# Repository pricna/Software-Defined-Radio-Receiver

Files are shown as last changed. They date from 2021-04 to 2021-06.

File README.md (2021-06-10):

# Software-Defined-Radio-Receiver
Software Defined Radio (SDR) receiver created in partial fulfillments of ENGR 357 "Engineering Electronics II" at Walla Walla University.

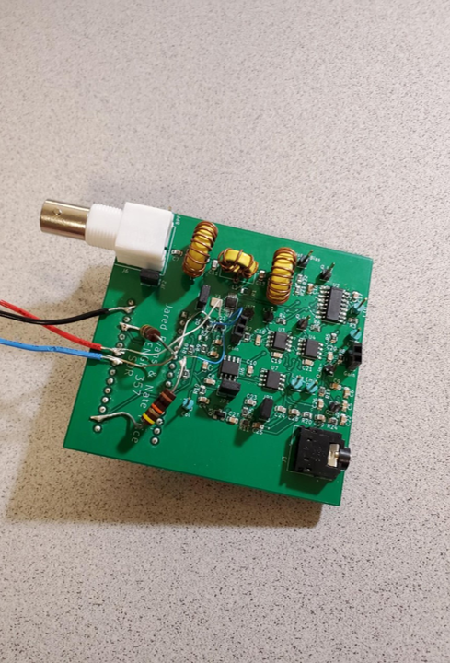
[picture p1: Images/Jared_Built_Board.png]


**Introduction:** This SDR receiver was designed to be simple and low cost, operate in the 10 MHz to 16 MHz frequency range, and also meet specific design criteria specified below. We ([Nate Price](https://github.com/pricna) and [Jared Evans](https://github.com/jred-KiCAD)), designed, assembled, and tested the SDR receiver to be used with a free open source SDR software, called Quisk. More information on the design, issues, testing, and software aspects of this project can be found on the [wiki page](https://github.com/pricna/Software-Defined-Radio-Receiver/wiki).

**Navigation:** 
- The Descriptions folder contains our circuit description for Miles
- The Images folder contains a variety of images of our board, PCB, and schematic
- The PCB Files folder contains some versions of our PCB, separated from the rest of the schematic files
- The Project Files folder contains our Bill of Materials and project files for v1.1
- The Schematic files folder contains pdfs of all of our schematic revisions, as well as project files for each of them
- The latest schematic can be found [here](https://github.com/pricna/Software-Defined-Radio-Receiver/tree/main/Schematic%20files/Project%20Files/v2.0/ENGR357_Project)

**Credits:** Much of this work builds on work described in [A Comparison of Affordable, Self-Assembled Software-Defined Radio Receivers Using Quadrature Sampling Down-Conversion](http://fweb.wallawalla.edu/~frohro/ClassHandouts/Electronics/A%20Comparison%20of%20Affordable,%20Self-Assembled%20%20Software-Defined%20Radio%20Receivers%20Using%20Quadrature%20Sampling%20Down-Conversion.pdf) by the authors [Caleb Froelich](https://github.com/froeca), [Konrad McClure](https://github.com/KonradMcClure), [Joshua Silver](https://github.com/JoshSilver8), [Jordyn Watkins](https://github.com/greenjacketgirl), and our professor, [Dr. Rob Frohne](https://github.com/frohro).

**Project Results:** We worked on two boards, one needs to have a FET replaced, which is a bit difficult with all the other connections we added to fix some PCB errors. It also might need further work, but it is unknown if there are more errors because the Arduino and Si5351 were not communicating. We were able to get the other board working. It produces I/Q signals 90 degrees out of face, has a sensitivity less than .1uV, and was successfully able to pick up signals when connected to the antenna with the Quisk software running. Take a look at [this video](https://www.youtube.com/watch?v=M_2Oau0vji8) to see the working radio!

## Further Information

(The information below is also covered in the [wiki page](https://github.com/pricna/Software-Defined-Radio-Receiver/wiki) (in sections). The wiki page also has some extra pages with information not in this document with milestones and generally useful information.

## 1. Hardware Design

## Block Diagram 
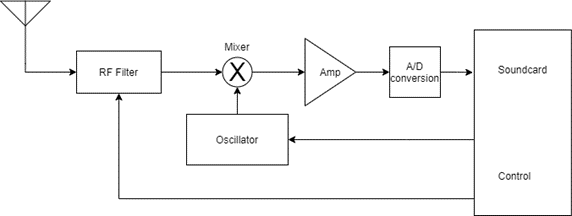
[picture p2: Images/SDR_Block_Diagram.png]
 

The block diagram was designed to help us get a better understanding of all the portions that needed to be designed for this project. Given that we had the benefit of seeing what other groups had previously worked on, figuring this out was relatively simple even though it does not fully match our final design.

## Bandpass Filter 
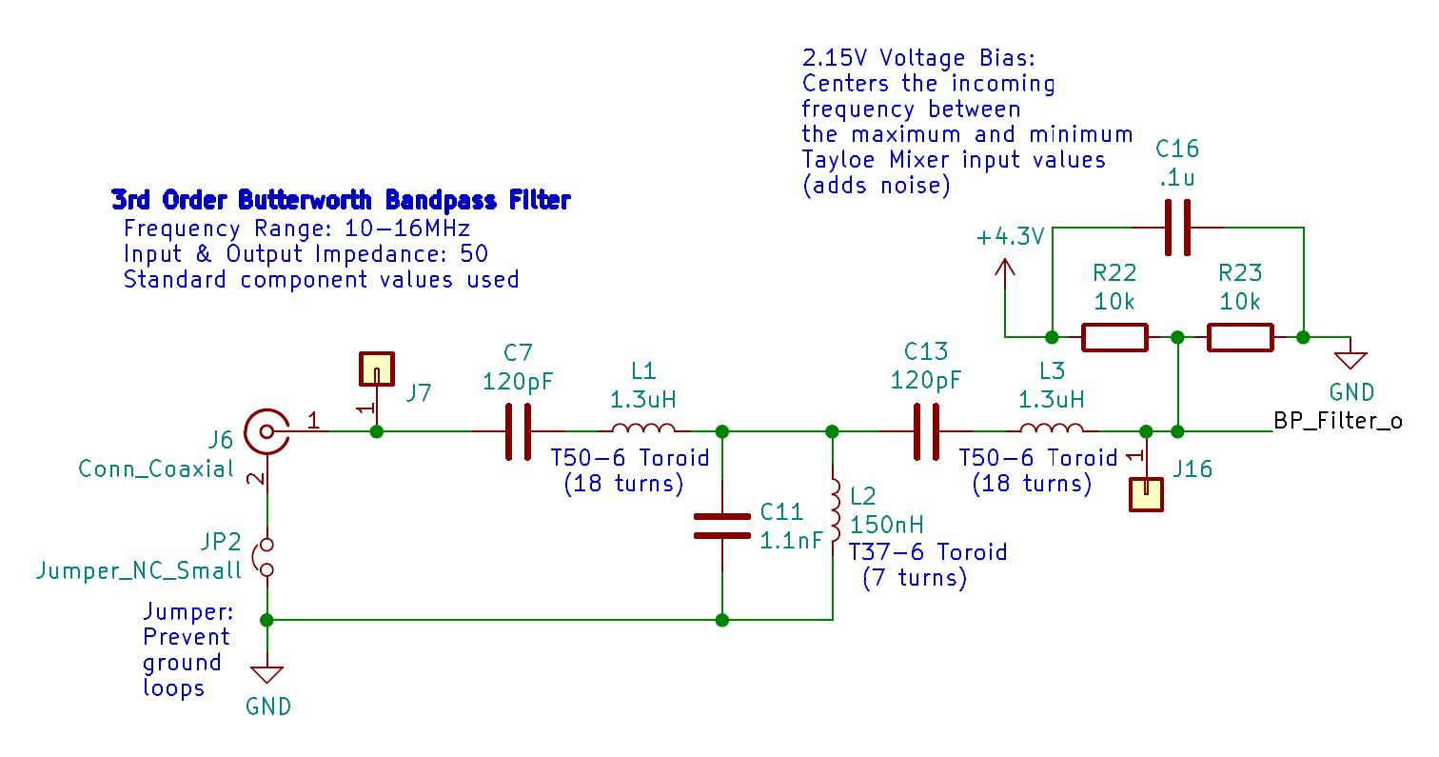
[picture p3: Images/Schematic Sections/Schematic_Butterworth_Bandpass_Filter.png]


The bandpass filter was partially based on the work done previously by [Caleb Froelich](https://github.com/froeca) and [Konrad McClure](https://github.com/KonradMcClure). We used the same tool that they used, [rf-tools](https://rf-tools.com/lc-filter/), to calculate the necessary values for a 3rd-order Butterworth bandpass filter for a lower cutoff frequency of 10 MHz and an upper cutoff frequency of 16 MHz. The number of turns for the toroids was determined to be 3nH per turns^2 for the Ts7-6 and 4nH per turns^2 for the T50-6. The 2.15V voltage bias part on the end is used to center the incoming frequency between the maximum and minimum Tayloe Mixer input values, which adds noise, but we ultimately determined that having that part is more useful here. 

**Calculations:**
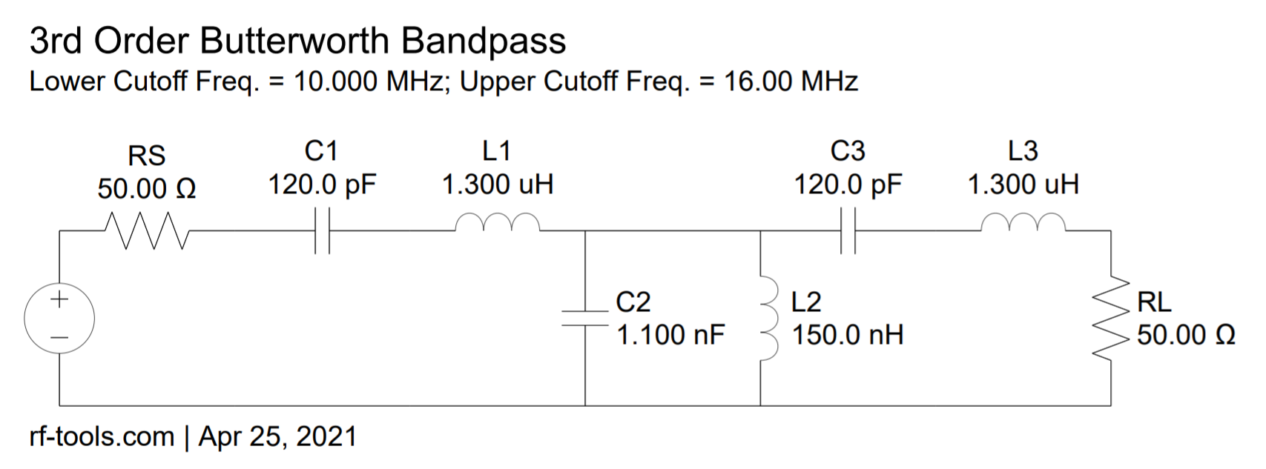
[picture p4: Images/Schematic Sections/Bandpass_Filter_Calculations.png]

  
## Instrumentation Amplifier 
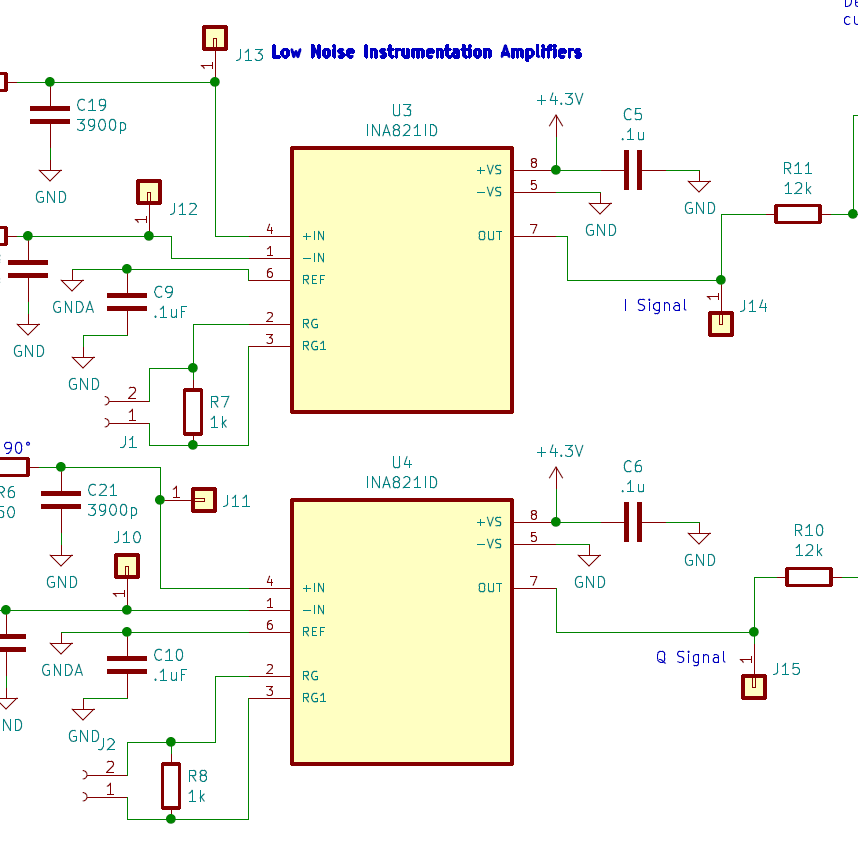
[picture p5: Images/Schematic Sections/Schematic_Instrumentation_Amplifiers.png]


The instrumentation design is very similar to the [Caleb](https://github.com/froeca) and [Konrad](https://github.com/KonradMcClure) design. They designed it to work in a way such that the 0° and 180° signals, and the 90° and 270° are are differentially summed by the INA821ID Instrumentation Amplifiers.

## Tayloe Mixer 
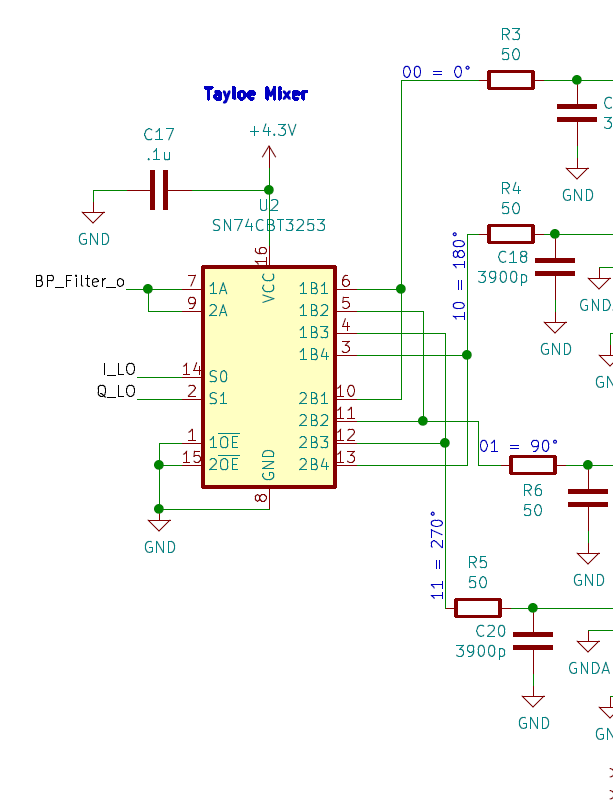
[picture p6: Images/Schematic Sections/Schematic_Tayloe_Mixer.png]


The Tayloe mixer design is once again very similar. We decided that we did not need to re-determine how to set up the connections to get 0° on 00, 90° on 01, and so on.

## Voltage Smoother 
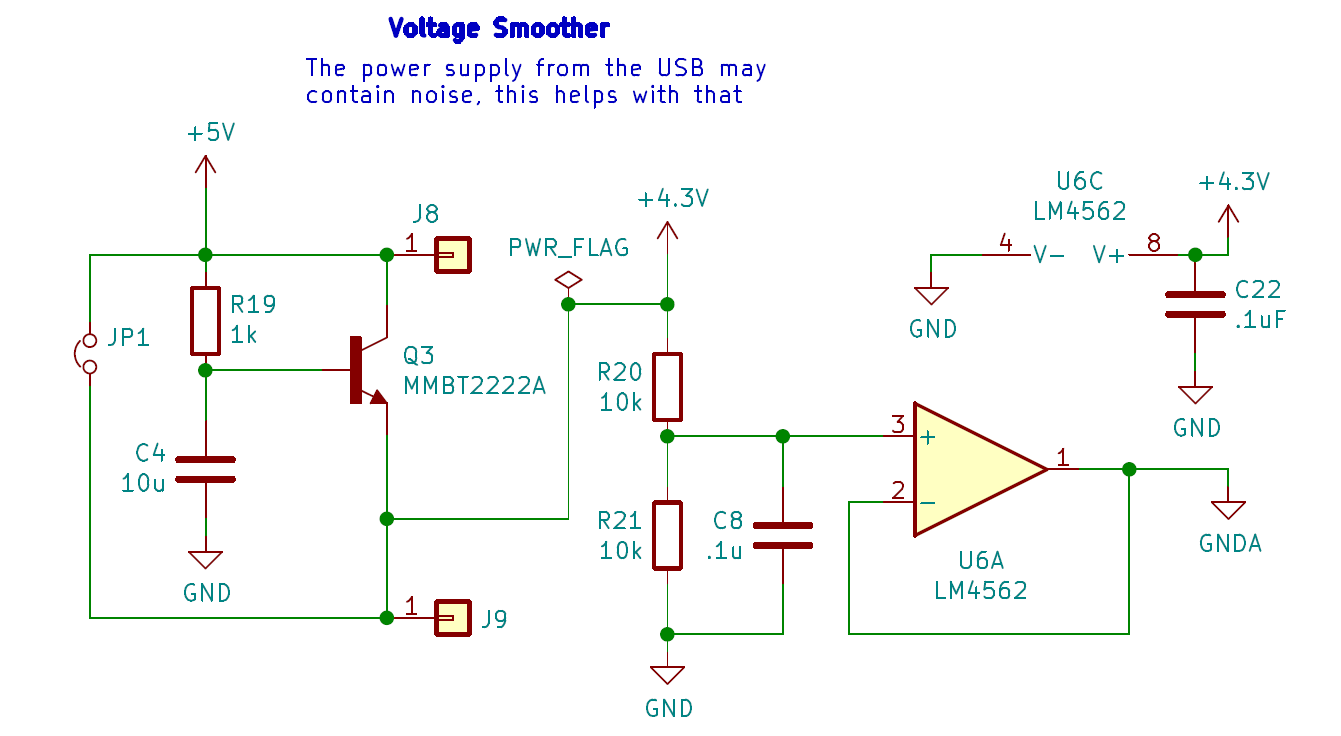
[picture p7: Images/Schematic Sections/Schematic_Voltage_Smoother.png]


Once again, this is something the previous group used to reduce some of the noise that resulted from the constant switching in the computer. Since for this project, some additional noise reduction seemed particularly useful, we pulled also used it for our design.

## Local Oscillator 
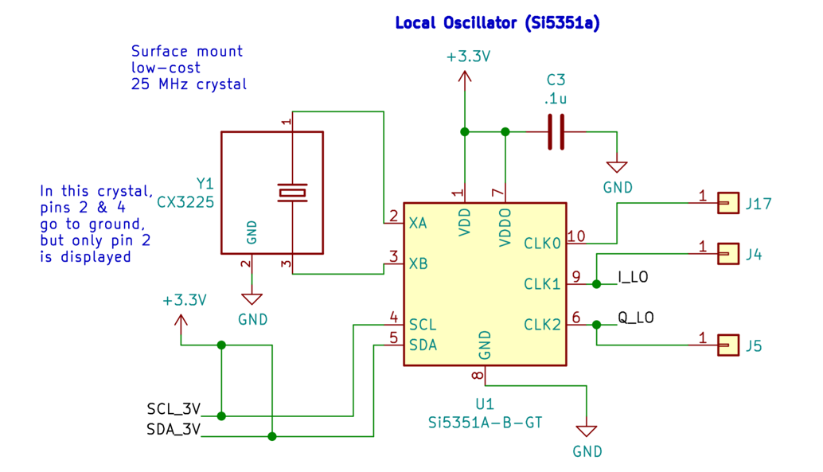
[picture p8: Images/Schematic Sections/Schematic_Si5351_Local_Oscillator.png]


As the previous group used a Johnson counter, the local oscillator needed to be updated for this project, since Dr. Frohne said it was unnecessary. A 3.3V connection was added to the SCL_3V and SDA_3V connections on the pins 4 and 5, a crystal was chosen because it was the frequency needed for the Si5351 chip, and the previous group did not use many surface mount components, so this schematic does. We also arbitrarily set our I/Q signals to CLK1 and CLK2. In a future redesign, it might be slightly easier to set up the software if the clocks are set to 0 & 1 instead.

## Voltage Converter 
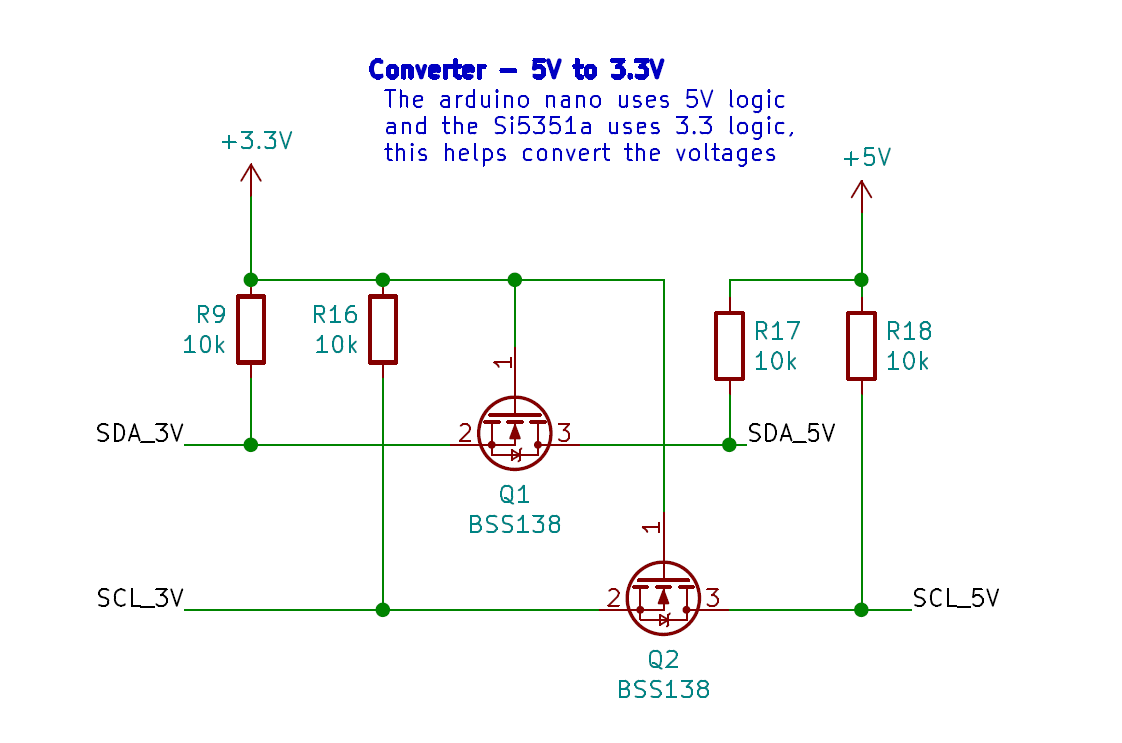
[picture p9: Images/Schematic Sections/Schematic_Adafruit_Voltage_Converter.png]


A voltage converter was added because with the different voltages needed for the oscillator and Arduino, we wanted to be sure nothing was burned up because an incorrect voltage was used. This design comes from the [Adafruit Si5351 design](https://learn.adafruit.com/assets/18765). This was one of the places where we originally made an error in the schematic that made its way to the PCB.

## Lowpass Filter
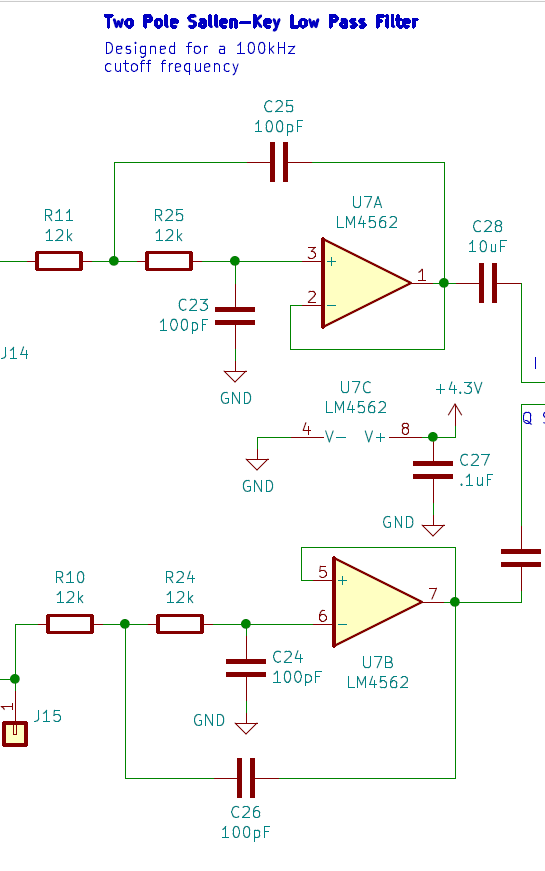
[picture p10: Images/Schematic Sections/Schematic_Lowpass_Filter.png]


Just like the bandpass filter, the lowpass filter was designed with assistance from online tools. This is one of the parts of our schematic that changed the most from the original design to the end result, but we ultimately decided on using a Sallen-Key Lowpass Filter that was calculated for a cutoff frequency of 100 kHz using [this online tool](http://sim.okawa-denshi.jp/en/OPseikiLowkeisan.htm). We also decided on using the LM4565 op amps for this (and the voltage smoother) because they were cheap and according to the datasheet, had a lower noise density than some of the other op amps we looked at.

## 2. Testing and Errors

## Basic Tests Done
The boards were constructed following our bring-up plan and Bill of Materials.

The first tests done were some basic continuity tests with a multimeter to confirm there were no major errors, such as a short between Vcc and ground, or shorts between pins on any of the smaller chips. We wound up eventually finding out that SDA and SCL were shorted, but that was determined after other tests were conducted.

One of the most useful tools for our testing was the program Logic, which we used with a Saleae Logic Analyzer connected to ground and the SDA and SCL pins on the Arduino. This was used because when we originally set up the [Arduino phase software](https://github.com/etherkit/Si5351Arduino/tree/master/examples/si5351_phase), we found that the I/Q signals were the default signals from our crystal. We updated the I2C address in the code from 0x60 to 0x62 to try and make it work, but that did not help. Hooking up the logic analyzer helped us determine that there were errors in our PCB because the Si5351 was not communicating with the Arduino. Those errors are detailed below in the **Errors** section.

When those errors were eventually fixed on Jared's board, we were able to get the proper devices communicating and confirm it with the logic analyzer. An oscilloscope was used to confirm that the Arduino code was changing the frequency, and properly offsetting the phase. We did not fix the communication issue on the other board, because that would require much more work (as detailed in the results page). The phase offset on Jared's board can be seen below. 

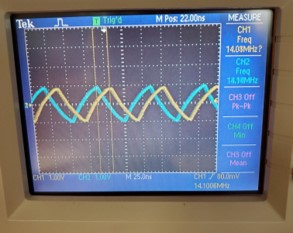
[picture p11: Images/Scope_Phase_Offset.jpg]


Also during our testing, the Bandpass filter was hooked up to a signal generator and oscilloscope to confirm that the connections were properly made. The results seemed good enough for the 10-16MHz range, so we decided it seemed to be working.

The final test needed before fully launching Quisk was to get the Arduino code that integrates with Quisk properly running. This wound up being a much more exhaustive undertaking than expected, because the code we used came from Dr. Frohne's untested code [here](https://github.com/frohro/IQ_SDR/tree/muSDR), and we struggled to get the correct phases output. Eventually, we determined with the help of Dr. Frohne that the frequency that set the proper phases needed to be multiplied by 100, and several instances of clocks 0&1 needed to be changed to clocks 0&2. With that updated, we were able to get the phases properly set.

## Errors 
Revealed by the testing process

Below are some images of some shorts that were discovered in our PCB. The appearance of these shorts was because of errors made in both our schematic and PCB. And since I (Nate) made the schematic, and Jared made the PCB, and we did not carefully check each others' work, we did not catch any obvious errors, such as the fact that SDA and SCL were obviously shorted. 

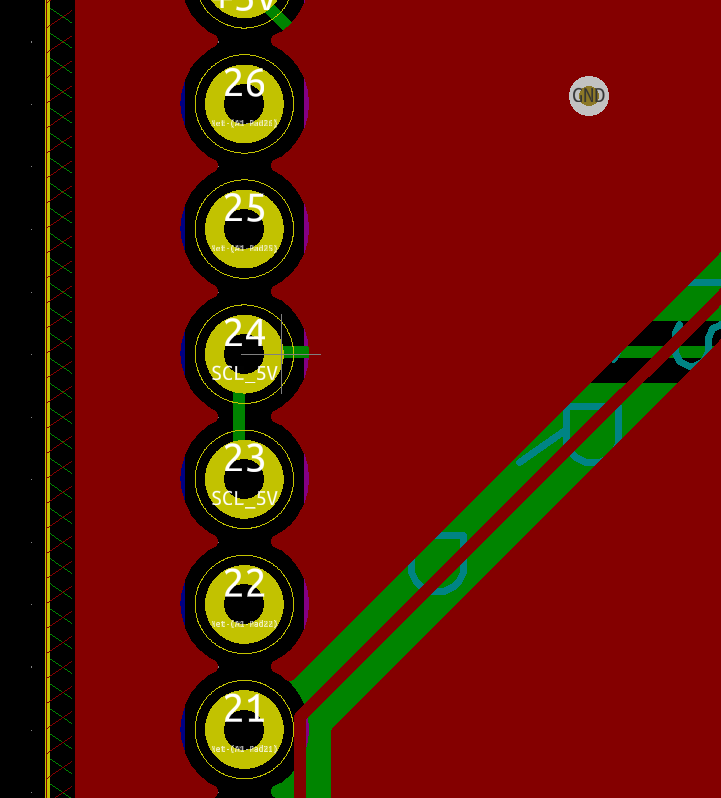
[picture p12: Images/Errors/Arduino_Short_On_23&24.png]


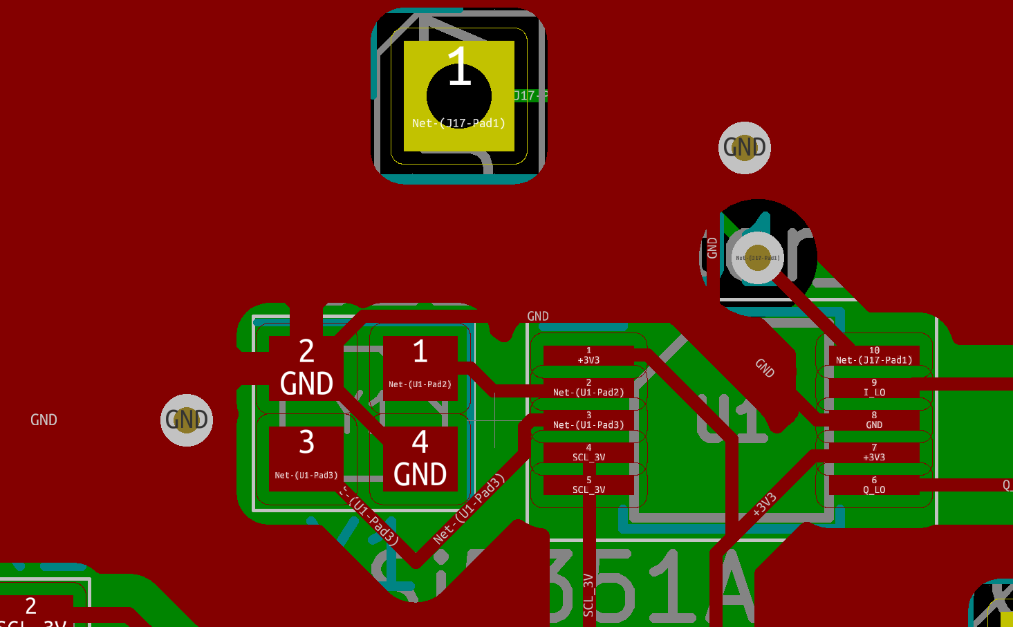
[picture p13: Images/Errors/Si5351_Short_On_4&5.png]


Here are some of the errors in the schematic that led to the errors in the PCB, and what was changed to fix them:

**Oscillator:**

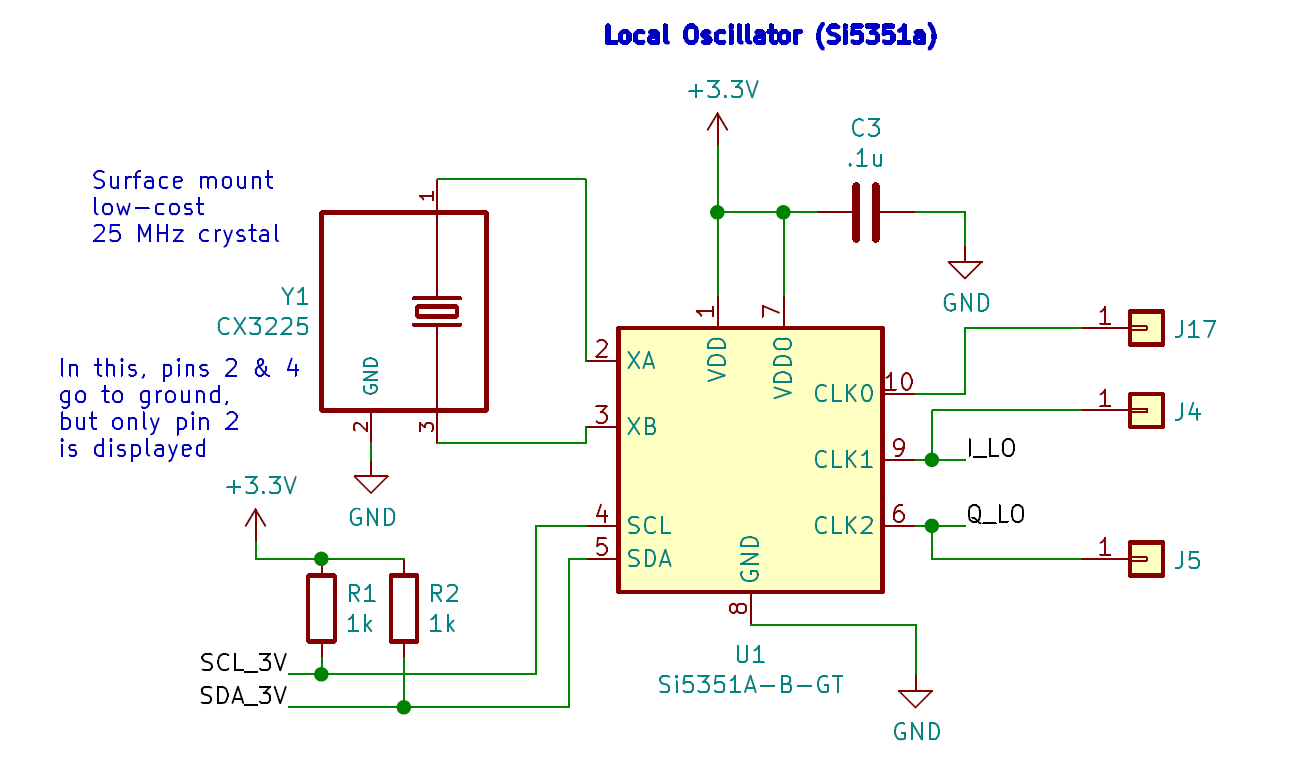
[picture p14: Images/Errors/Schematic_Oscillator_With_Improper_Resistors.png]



As can be seen in the pictures above, pull-up resistors were incorrectly used. 

**Voltage Converter:**

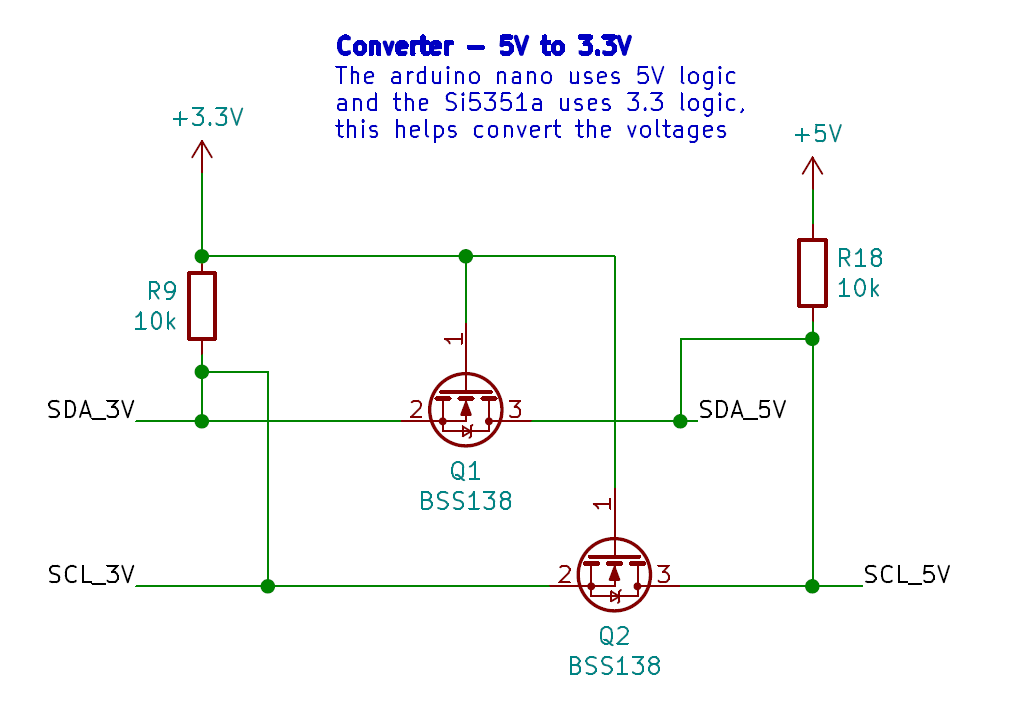
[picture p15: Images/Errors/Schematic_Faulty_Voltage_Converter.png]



As can be seen, an incorrect adjustment to the resistors in the Adafruit voltage converter was made. This was one of the bigger issues for how our PCB turned out.

## 3. Software
(and simulations)

## Simulations

We simulated our work using LTspice. Much of this work is based on the work previously done by Dr. Frohne and the other groups, but these simulations can be found [here](https://github.com/pricna/Software-Defined-Radio-Receiver/tree/main/LTspice%20Simulation%20Files) in the repository. Jared primarily focused on getting the simulations going. The following is an LTspice screenshot of a noise simulation that seemed to get decent results. The instrumentation amplifiers used are not the ones we used because of difficulties in finding the proper ones, and we did not fully integrate everything all of our circuitry into all of our simulations.

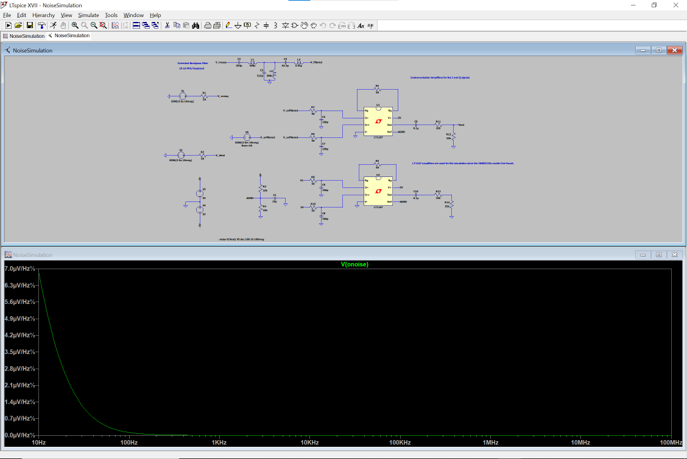
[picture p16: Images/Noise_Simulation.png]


## Logic

As mentioned in the Testing and Errors page, the program Logic was used to check I2C signals. To set it up, hook up ground and SDA/SCL connections to a logic analyzer, set up an I2C analyzer in the software, load the Arduino phase code with the correct I2C address, and then press run in the software. It is a good idea to zoom out while it is running to confirm that signals are coming in, and then stop it and zoom in to check the signal. This is what it looks like when the I2C there is no acknowledgement.

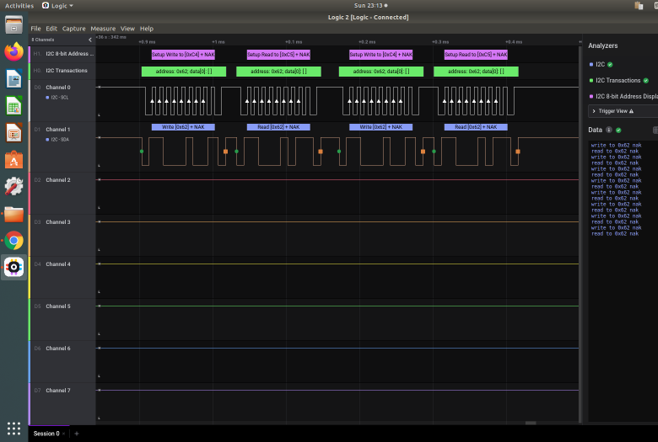
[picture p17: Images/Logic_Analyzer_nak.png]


## Arduino

The Arduino code was also mentioned previously on the Testing and Errors page, so to reiterate some of what was said. To test just the phase of the I/Q signals, [this example code can be used](https://github.com/etherkit/Si5351Arduino/tree/master/examples/si5351_phase). To use it with the board designed for this project, instances of clocks 0 & 1 need to be changes to clocks 1 & 2. Then for the overall Quisk code, modifications had to be made to Dr. Frohne's code to get it working with the code. Once again the clocks had to be changed, and some frequencies updated. Here is a screenshot of a portion of the changed code.

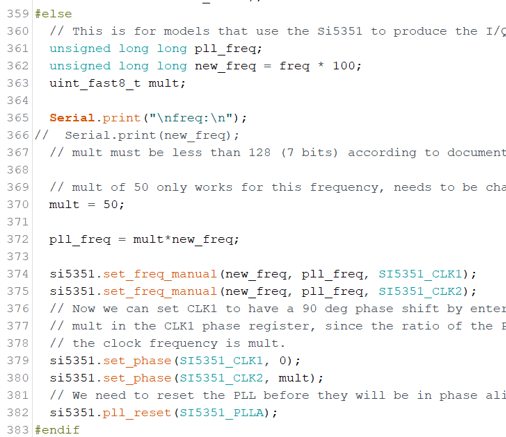
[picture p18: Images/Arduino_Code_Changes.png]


## Quisk

To set up Quisk, follow the installation steps detailed on [this page](https://james.ahlstrom.name/quisk/docs.html#Installation). Once Quisk is able to be executed, set up a softrock fixed radio with the quisk_conf_openradio.py config file. The changes made to the config file depend on the OS, but for this project, we set openradio_serial_port = "COM3" which is where the Arduino was plugged into the computer. We also changed the baud rate on the port to 57600 to match the baud rate in the software. We found that it is much easier to use Quisk if the soundcard and Arduino are plugged into a computer/laptop with multiple ports. If Quisk is properly set up, adjusting the frequency should adjust the I/Q frequencies in the board, which we confirmed with the oscilloscope. With that working, and an antenna set up, we were able to get good results, such as this:

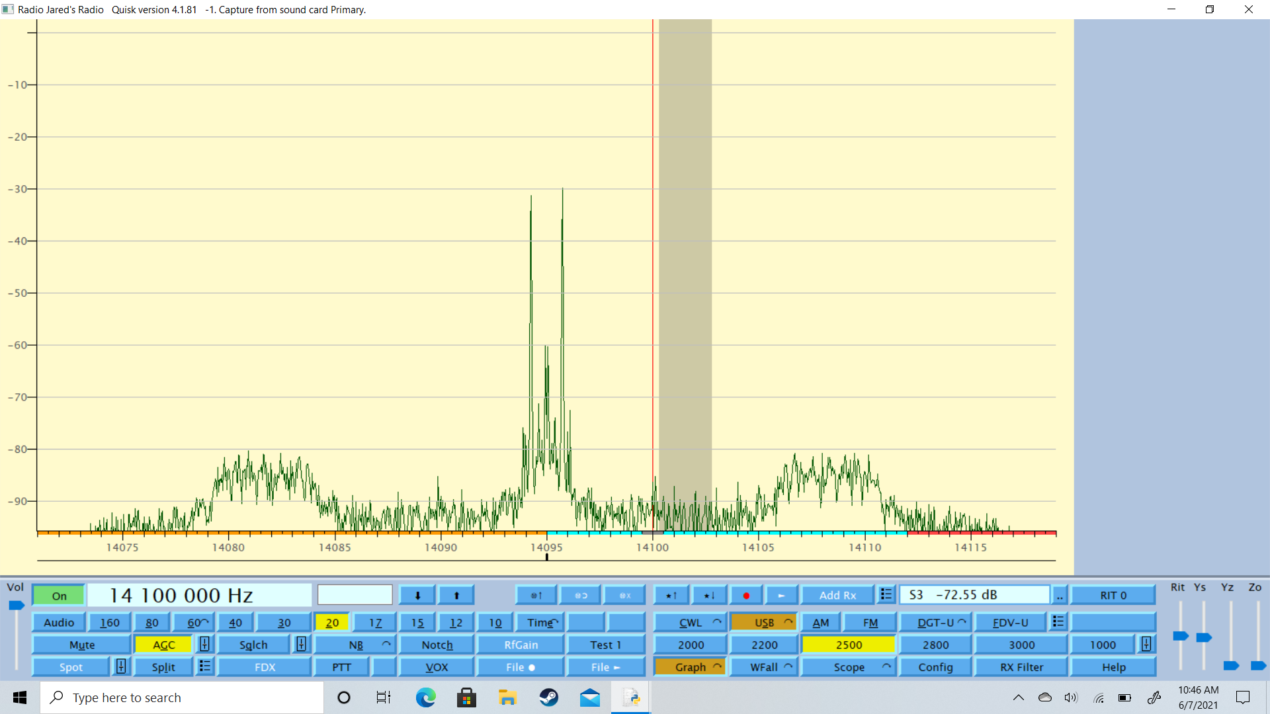
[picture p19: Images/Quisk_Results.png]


Also note that with the version of the software we were using, we incorrectly got error messages when there were no errors when we launched Quisk. Some of the Quisk setup steps were glossed over a little bit, so for more information on that either look at the installation instruction link above, or check [Konrad McClure's documentation](https://github.com/KonradMcClure/SDR_Receiver) for some additional useful information.

## 4. Results

## Nate's results
The software was changed to set the I2C address to 0x62 as per the data sheet for our Si5351. After connecting the logic analyzer, and learning that there was no acknowledgement, and trying to make additional corrections, it became clear that there was some other issue in the board.



Dr. Frohne helped determine that the issue was with one of the FETs that we had soldered several connections to.
The best ways to fix the error are:
- Design a new PCB, have it made, solder everything again.
- Use one of the extra broken PCB’s to start again, knowing which fixes are needed.

Either way requires a lot of time desoldering and then soldering again. Ultimately decided to make sure Jared’s board worked, which wound up requiring a large amount of collaboration. The board in it's current, broken state are shown below.

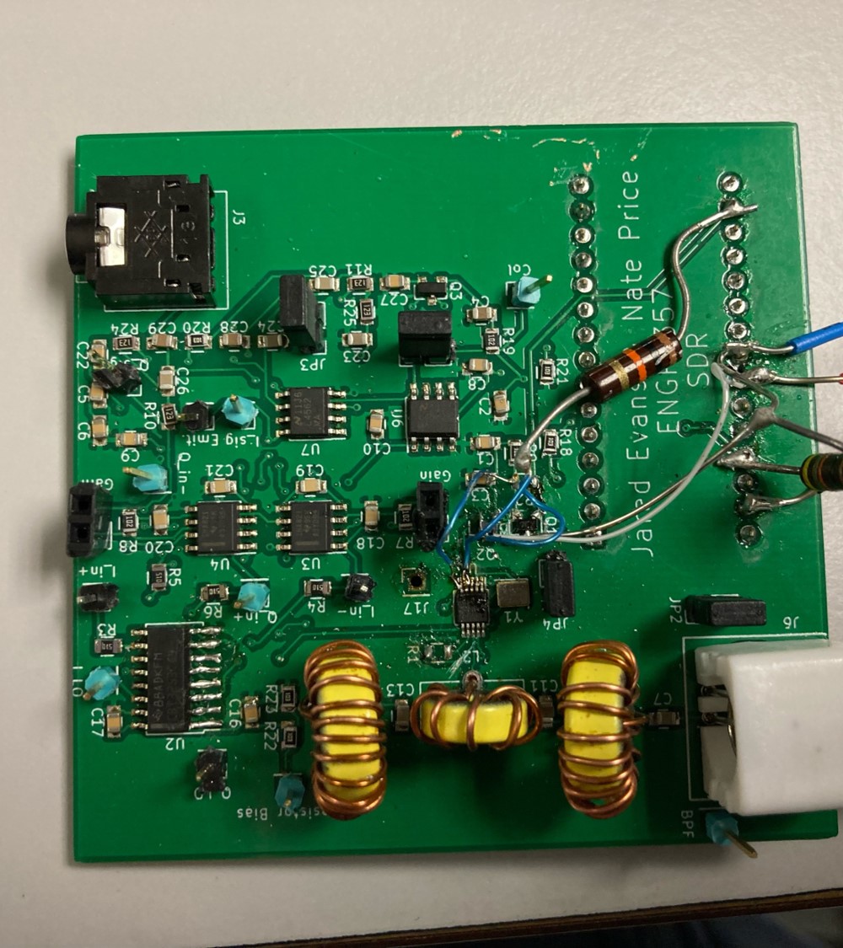
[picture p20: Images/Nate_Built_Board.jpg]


## Jared's results

We used the logic analyzer to confirm that on this board, the Si5351 communicates with Arduino. We used an oscilloscope to confirm that we could set the phases using [Arduino code](https://github.com/etherkit/Si5351Arduino/tree/master/examples/si5351_phase). On the signal generator we hooked up to the board, we found the sensitivity to be less than 0.1uV. Also, with Quisk set up, we found the image rejection to be approximately 3 dB. Though the most important result, is that we were able to tune Quisk to pick up a signal with the antenna connected. 

A video of a signal we picked up can be found [here](https://www.youtube.com/watch?v=M_2Oau0vji8).

And a picture of the fully constructed and working board can be found below:



Finally, here is a picture of Quisk running, and picking up a signal:



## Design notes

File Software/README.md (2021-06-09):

**Arduino Code Description:**
This is with my modified version of the code. Get the latest version of the code from Dr. Frohne [here](https://github.com/frohro/IQ_SDR/tree/muSDR/Quisk)

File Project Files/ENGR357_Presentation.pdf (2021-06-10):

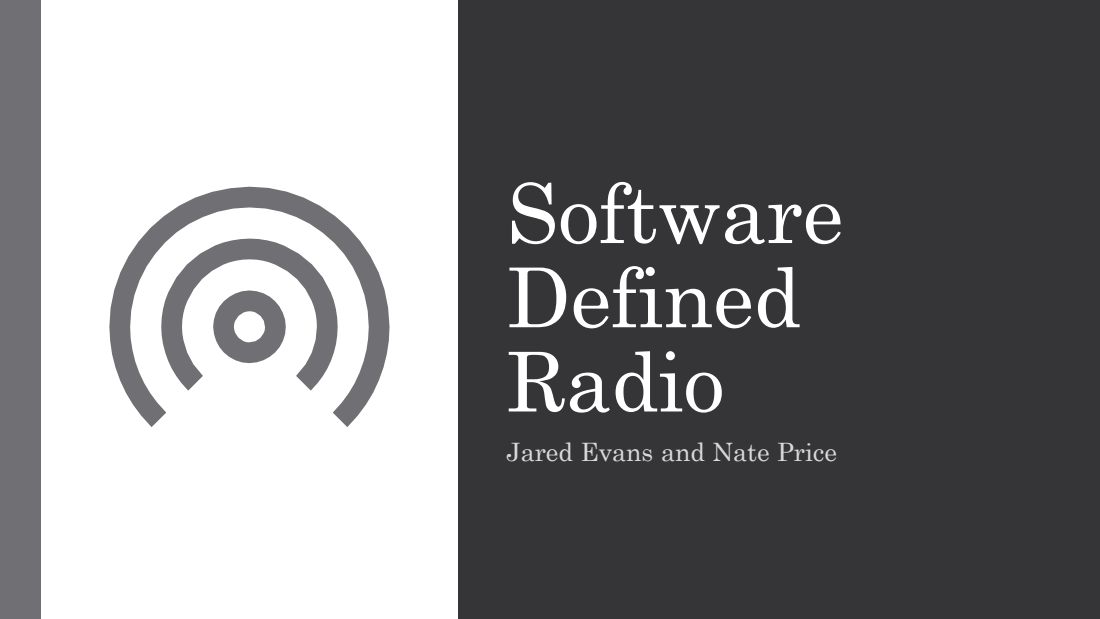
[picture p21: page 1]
Software Defined Radio

Jared Evans and Nate Price

## What is a Software Defined Radio (SDR)?

## - It is a radio receiver controlled by software implemented using an

Arduino in the case of this project.

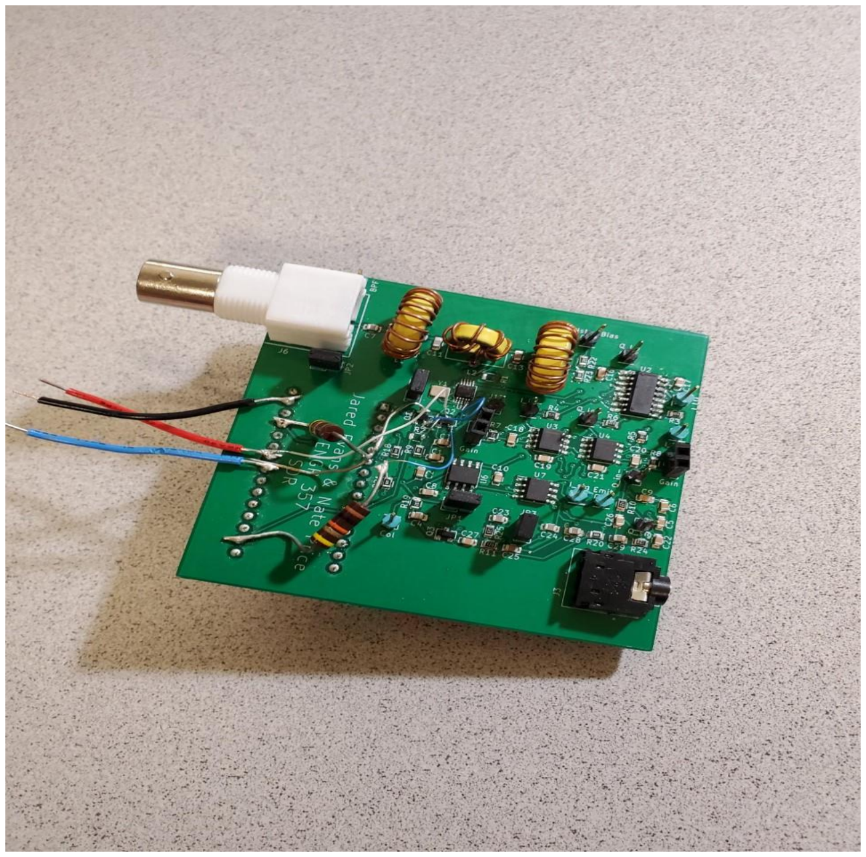
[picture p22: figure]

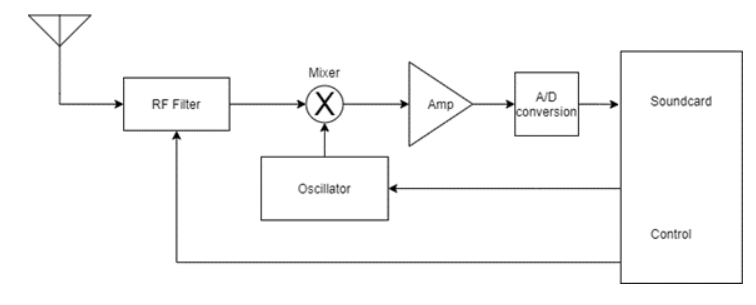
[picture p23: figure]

# Block Diagram

# Bandpass Filter


- Frequency Range: 10-16 MHz
- Based on Caleb Froelich and Konrad McClure’s bandpass filter
- Values calculated using rf-tools.com


## Instrumentation Amplifier


# Tayloe Mixer

# Voltage Smoother


- Based on Caleb Froelich and Konrad McClure’s voltage smoother
- Modified to use an LM4562 op-amp

# Local Oscillator

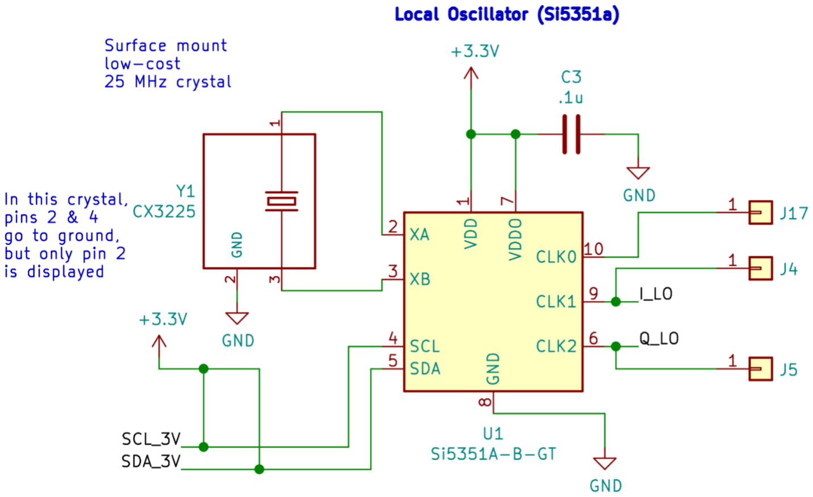
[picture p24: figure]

- Originally incorrectly used resistors between +3.3V and ground

# Voltage Converter


- Design comes from Adafruit
- Originally incorrectly tried to use fewer resistors

# Lowpass Filter

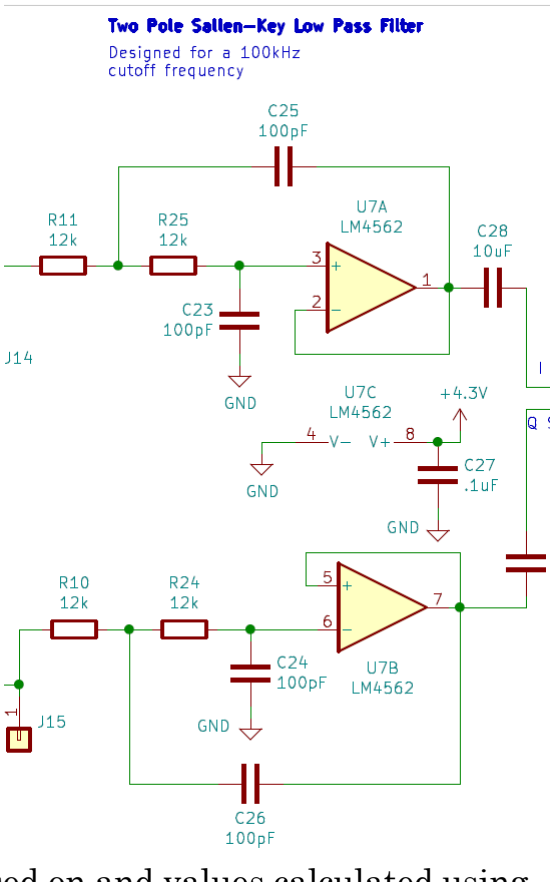
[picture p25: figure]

- Design based on and values calculated using http://sim.okawa-denshi.jp/en/OPseikiLowkeisan.htm

# Simulations

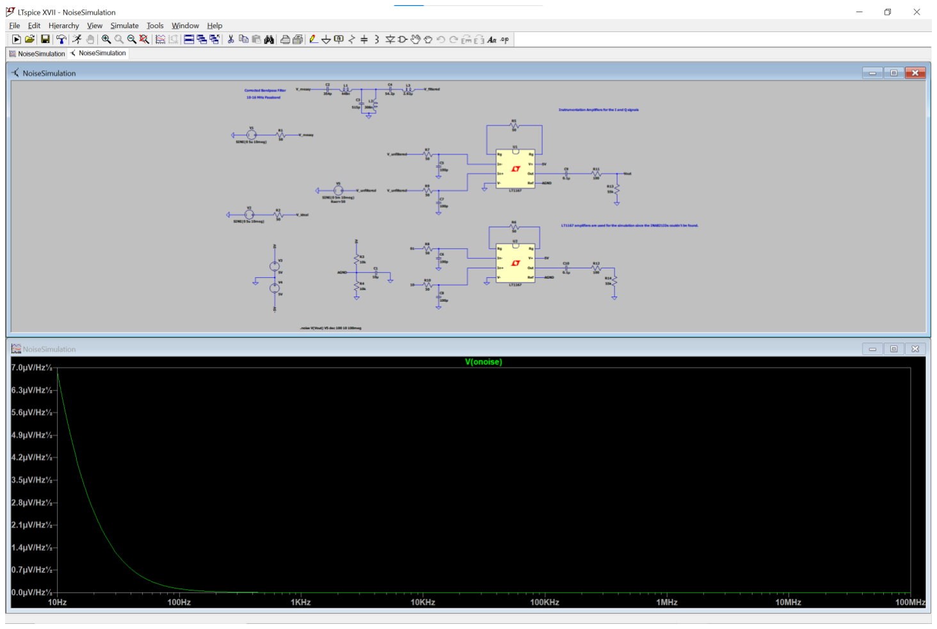
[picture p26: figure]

- This was one of our noise simulations

# PCB

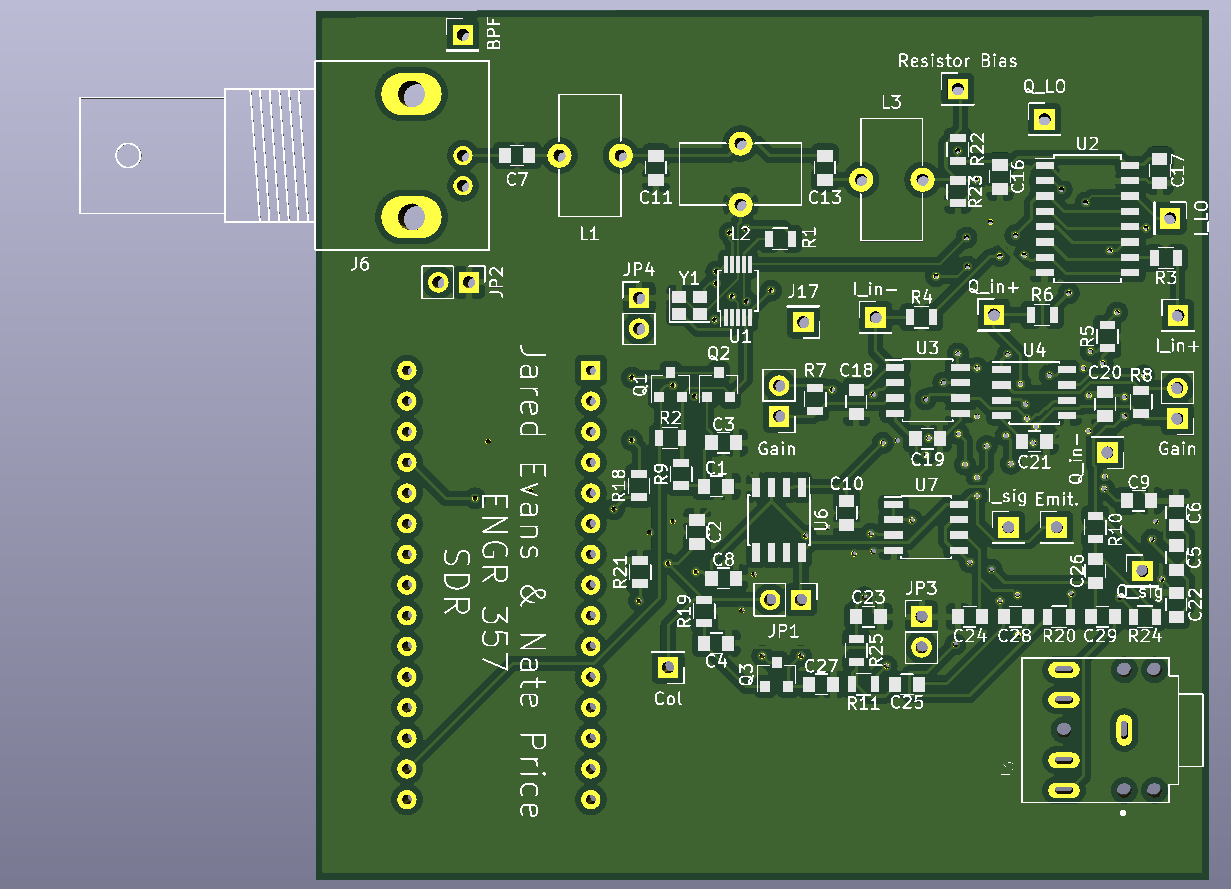
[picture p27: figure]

Tip: Check your PCB connections carefully!

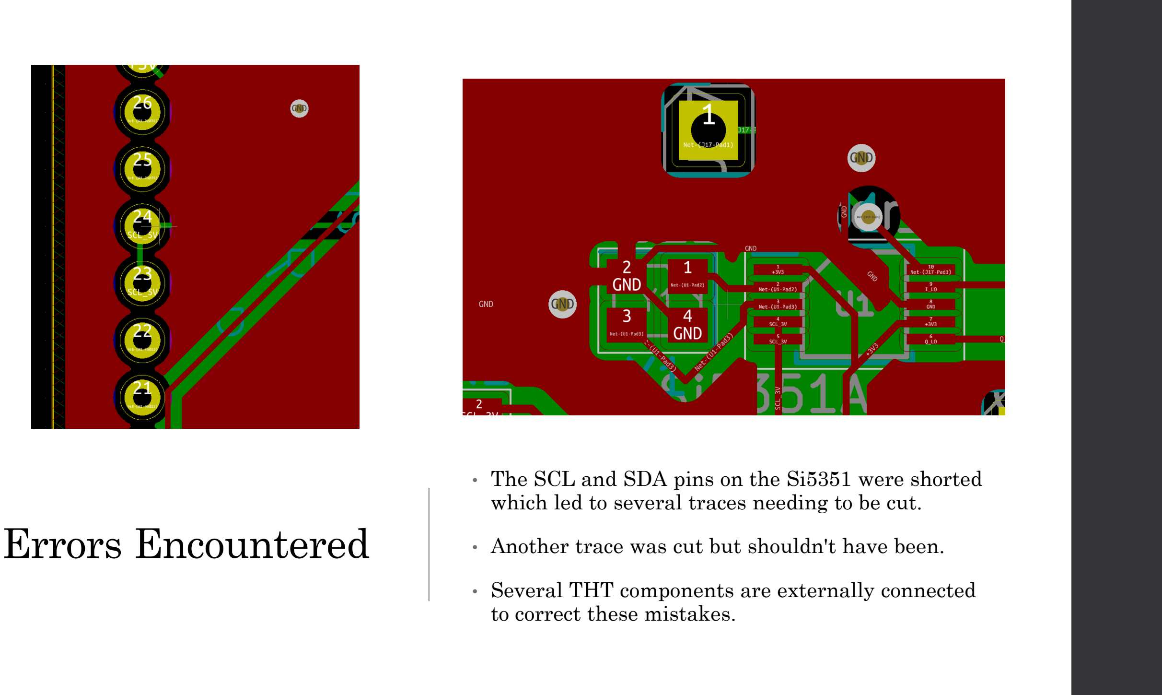
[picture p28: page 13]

# Errors Encountered

- The SCL and SDA pins on the Si5351 were shorted which led to several traces needing to be cut.
- Another trace was cut but shouldn't have been.
- Several THT components are externally connected to correct these mistakes.

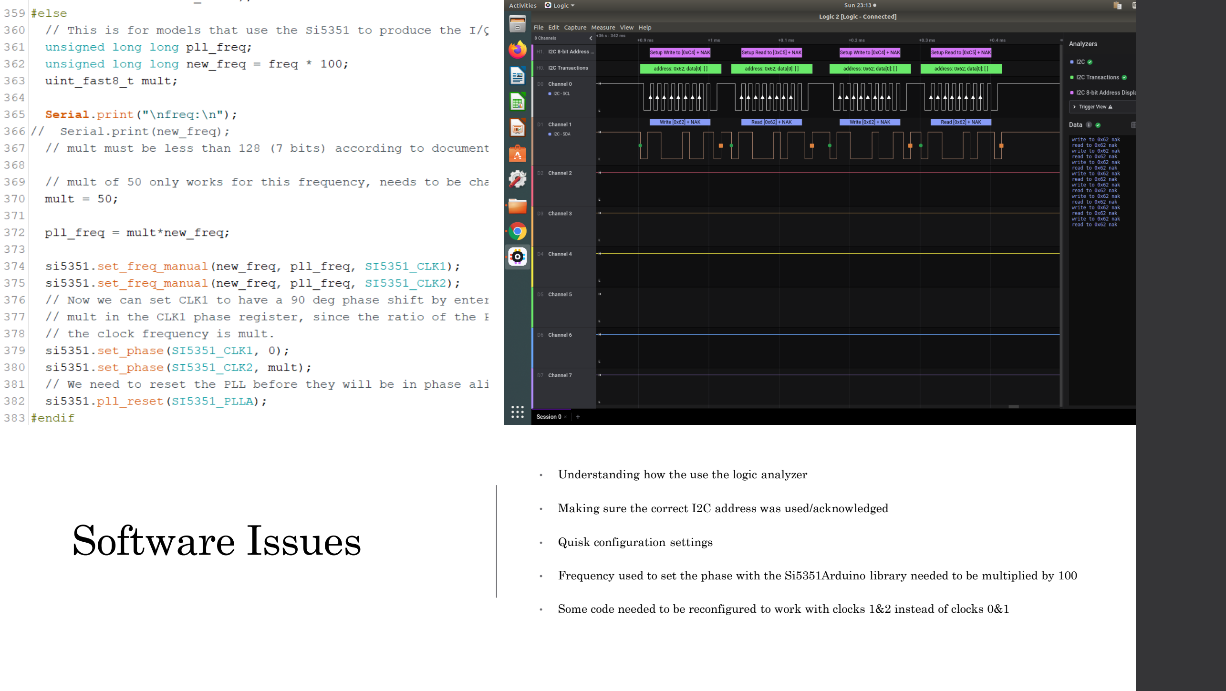
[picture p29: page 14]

# Software Issues

- Understanding how the use the logic analyzer
- Making sure the correct I2C address was used/acknowledged
- Quisk configuration settings
- Frequency used to set the phase with the Si5351Arduino library needed to be multiplied by 100
- Some code needed to be reconfigured to work with clocks 1&2 instead of clocks 0&1

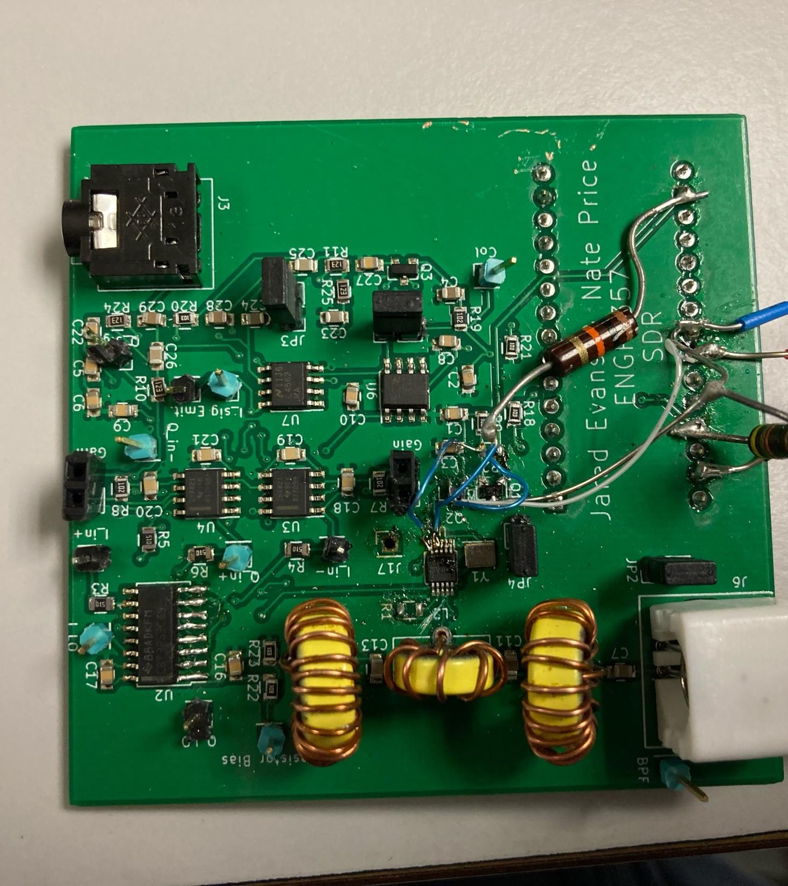
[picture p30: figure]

# Results – Nate’s Board

- I2C address 0x62 “nak”
- Would need to replace the FET where many soldering fixes were made
- Best ways to fix it:
- Design a new PCB, have it made, solder everything again
- Use one of the extra broken PCB’s to start again, knowing which fixes are needed
- Either way requires a lot of time desoldering and then soldering again
- Ultimately decided to make sure Jared’s board worked

# Results – Jared’s Board

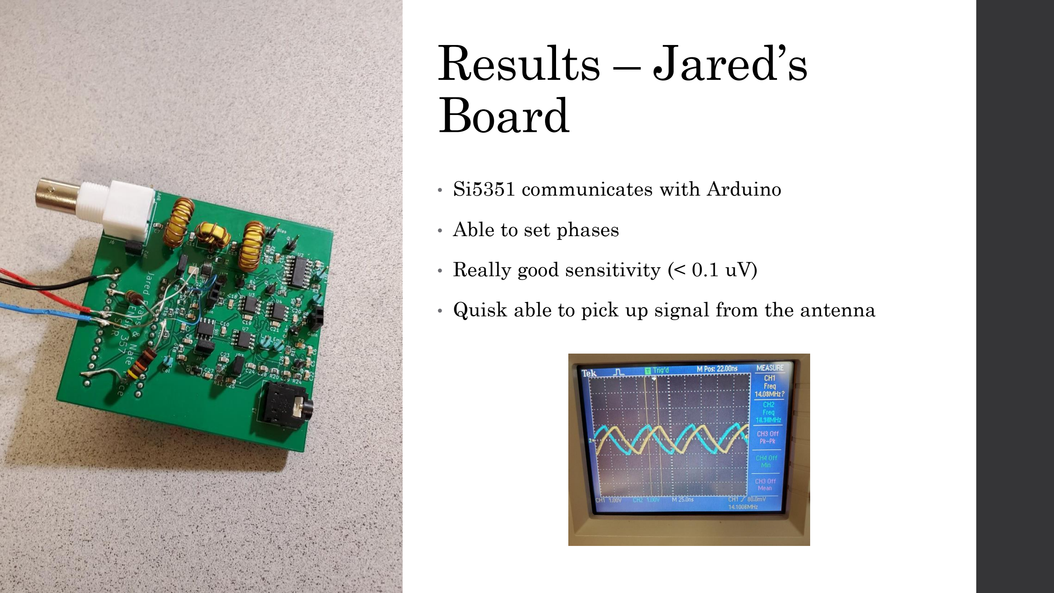
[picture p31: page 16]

- Si5351 communicates with Arduino
- Able to set phases
- Really good sensitivity (< 0.1 uV)
- Quisk able to pick up signal from the antenna

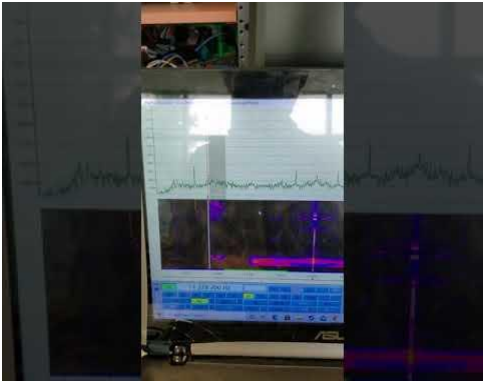
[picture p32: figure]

# Video

It's a bit difficult to see on the video, but the frequency
running when this video was being recorded was
14.2787 MHz. Also, while it's a little hard to hear, we could hear someone who sounded
like he was asking about
practicing law in a "public sense".

# Lessons Learned

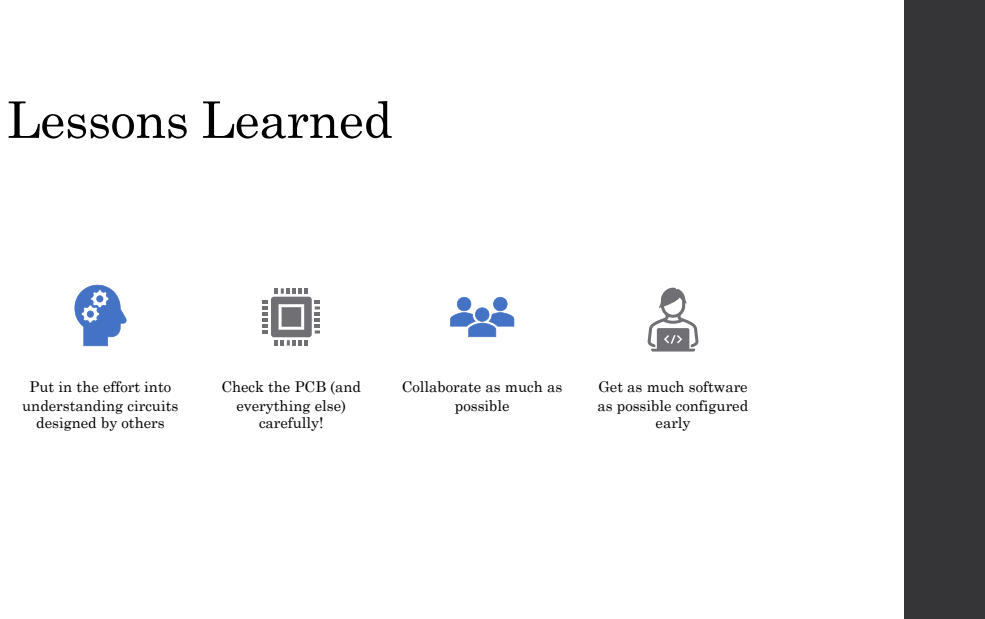
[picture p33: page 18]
possible; early

Put in the effort into
understanding circuits
designed by others

Check the PCB (and
everything else)
carefully!

Collaborate as much as

Get as much software
as possible configured

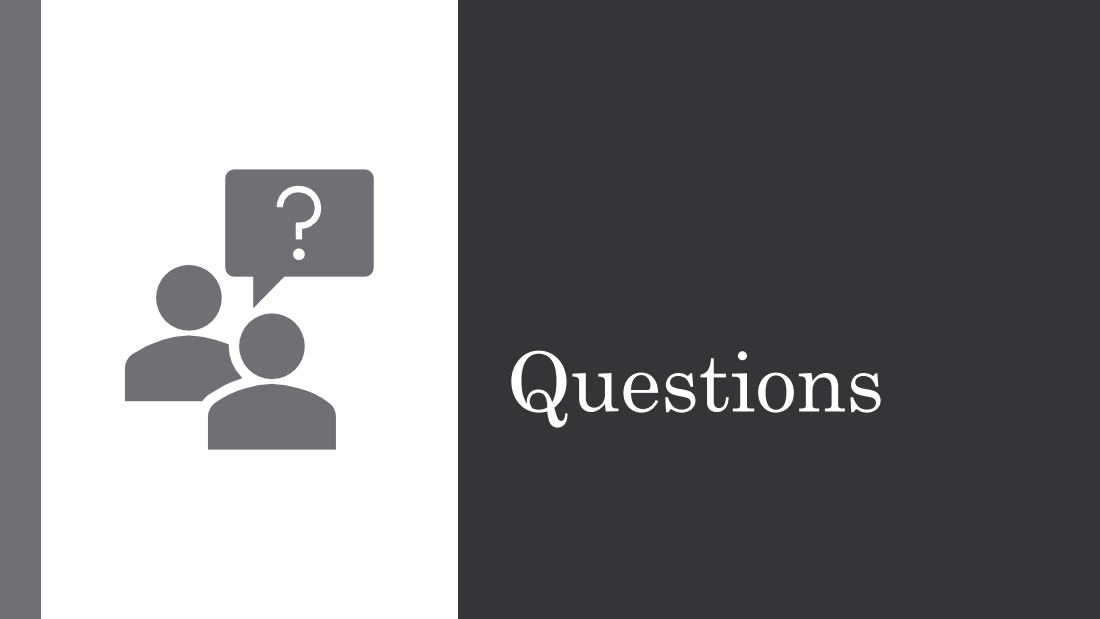
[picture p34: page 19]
Questions

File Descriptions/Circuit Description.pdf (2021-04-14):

Jared Evans & Nate Price | ENGR 357 – Milestone 3 | 4/13/21

Circuit Description:

Currently our design features a Tayloe Mixer, Butterworth bandpass filter, instrumentation amplifier, S15351A local oscillator, and will likely have Arduino Nano connections. Ideally, the design will support 12-16MHz and will use a soundcard to integrate with SDR software. Also note that currently many of the values are either random or based off of the work on previous classes, such as the work shown in the text for this class. For the bandpass filter, the plan is to use an online calculator to refine the values we have. The necessary values should be acquired shortly, it is just a matter of needing time to refine what we have already. All work at this point is subject to change.

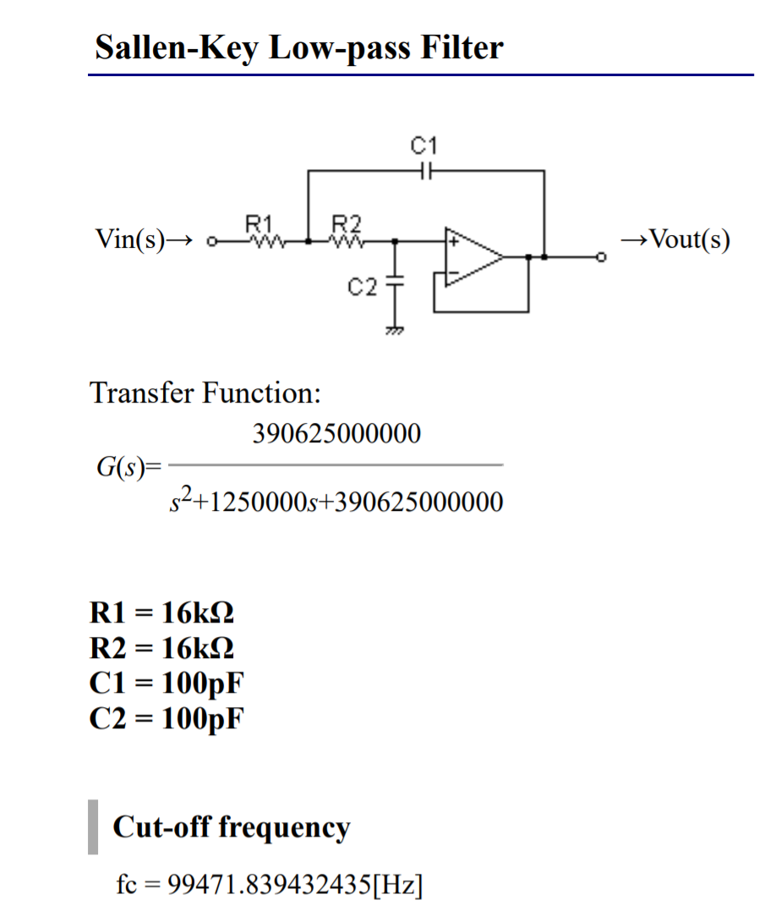
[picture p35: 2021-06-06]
Images/Schematic Sections/Lowpass_Filter_Calculations.png

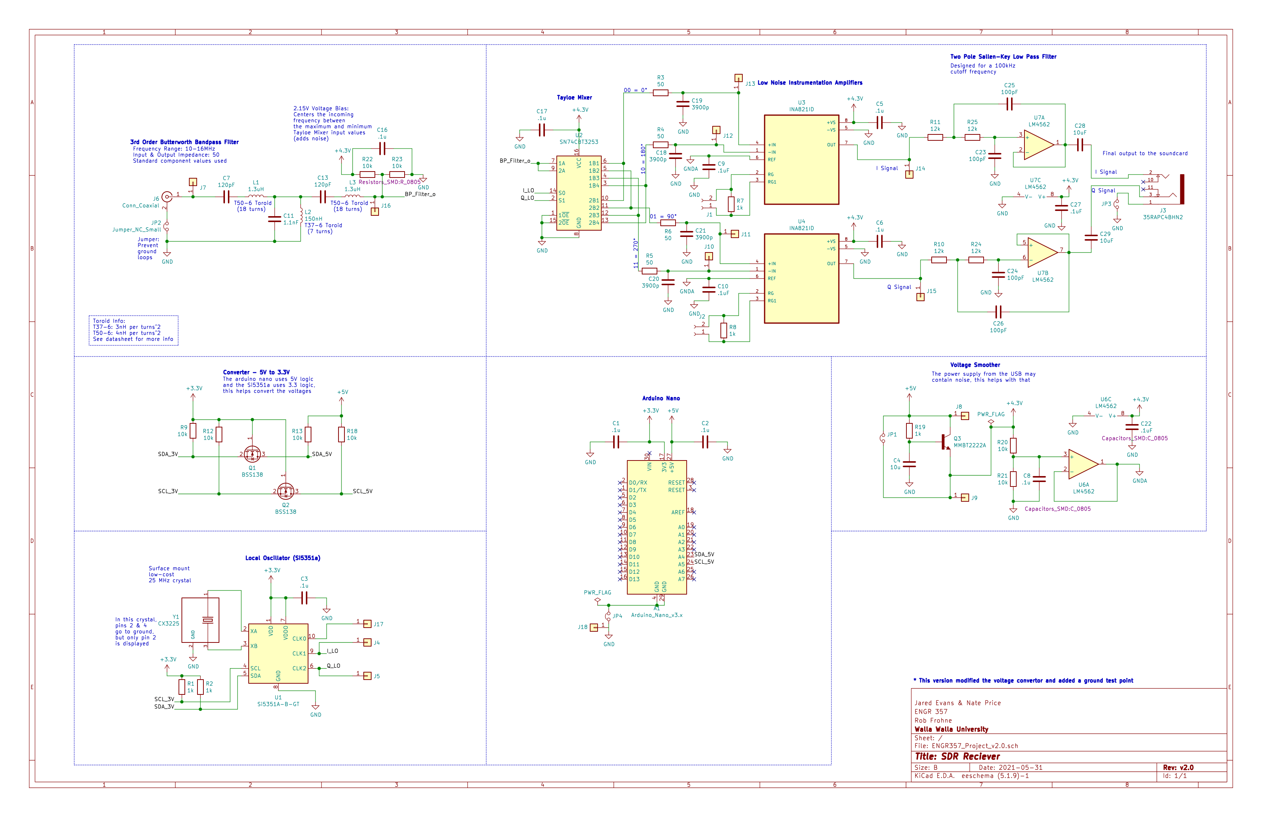
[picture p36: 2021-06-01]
Images/SDR_Schematic_v2.0.png

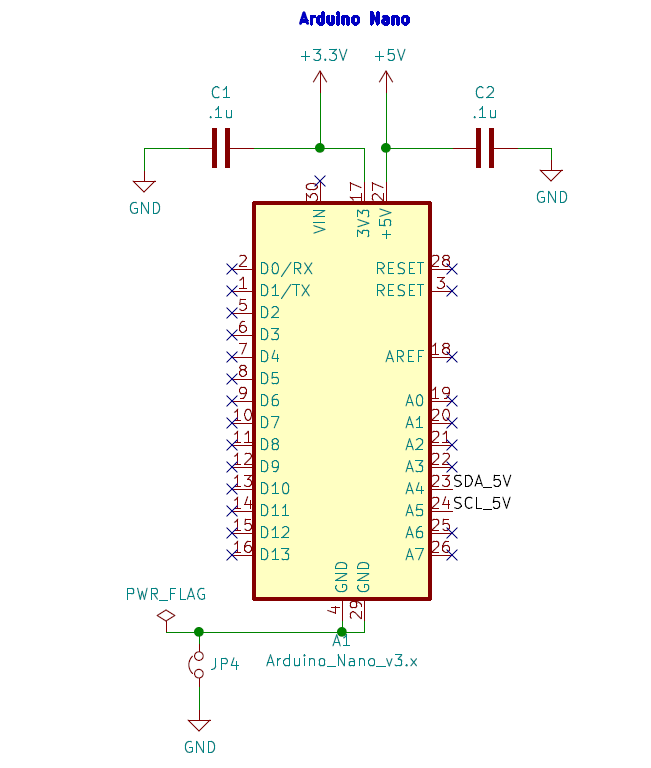
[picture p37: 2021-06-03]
Images/Schematic Sections/Schematic_Arduino.png

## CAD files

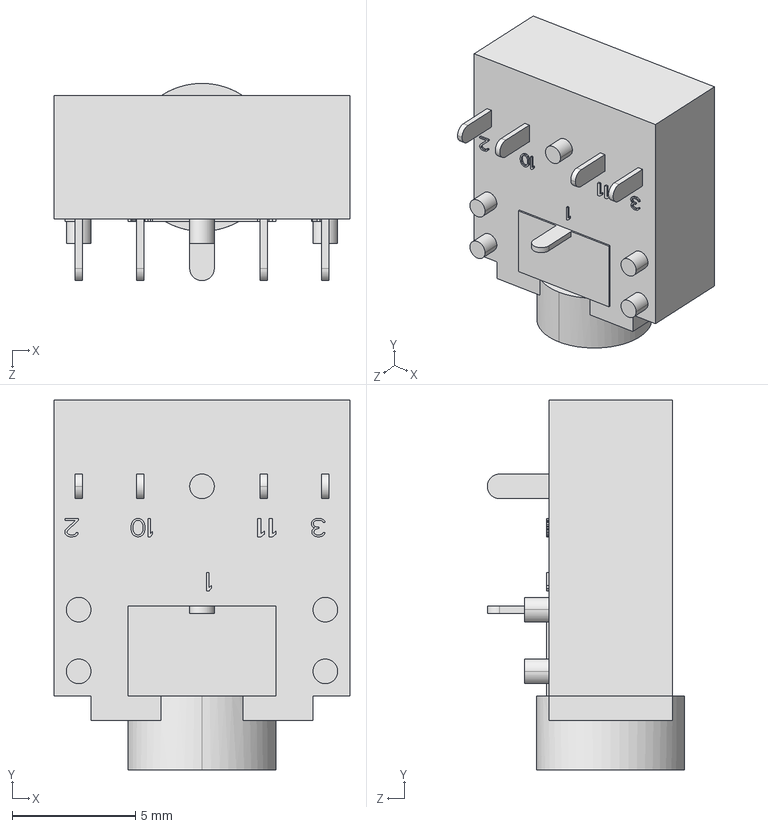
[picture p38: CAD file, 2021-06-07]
Schematic files/Project Files/v2.0/ENGR357_Project/35RAPC4BHN2.step
12.0 x 15.0 x 8.00 mm

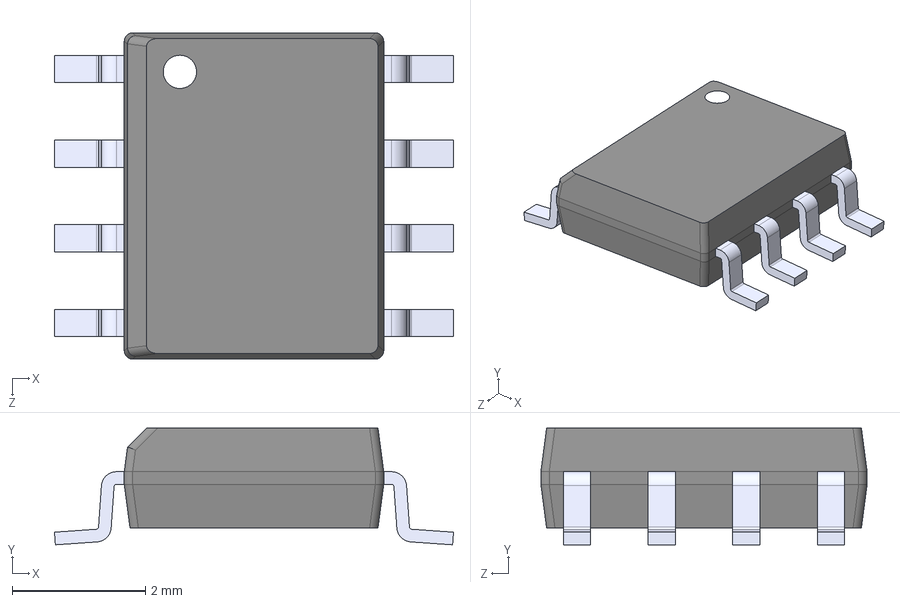
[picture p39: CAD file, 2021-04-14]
Schematic files/Project Files/v2.0/ENGR357_Project/INA821ID.step
5.99 x 1.75 x 4.90 mm

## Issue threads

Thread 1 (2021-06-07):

I2C level converter is not correct.

frohro, 2021-06-07:
Hi Nate and Jared,
Your I2C needs to be fixed on your schematic and PCB layout.  The SDA and SCL are shorted together, and you did not put pull-up resistors in properly.
Rob

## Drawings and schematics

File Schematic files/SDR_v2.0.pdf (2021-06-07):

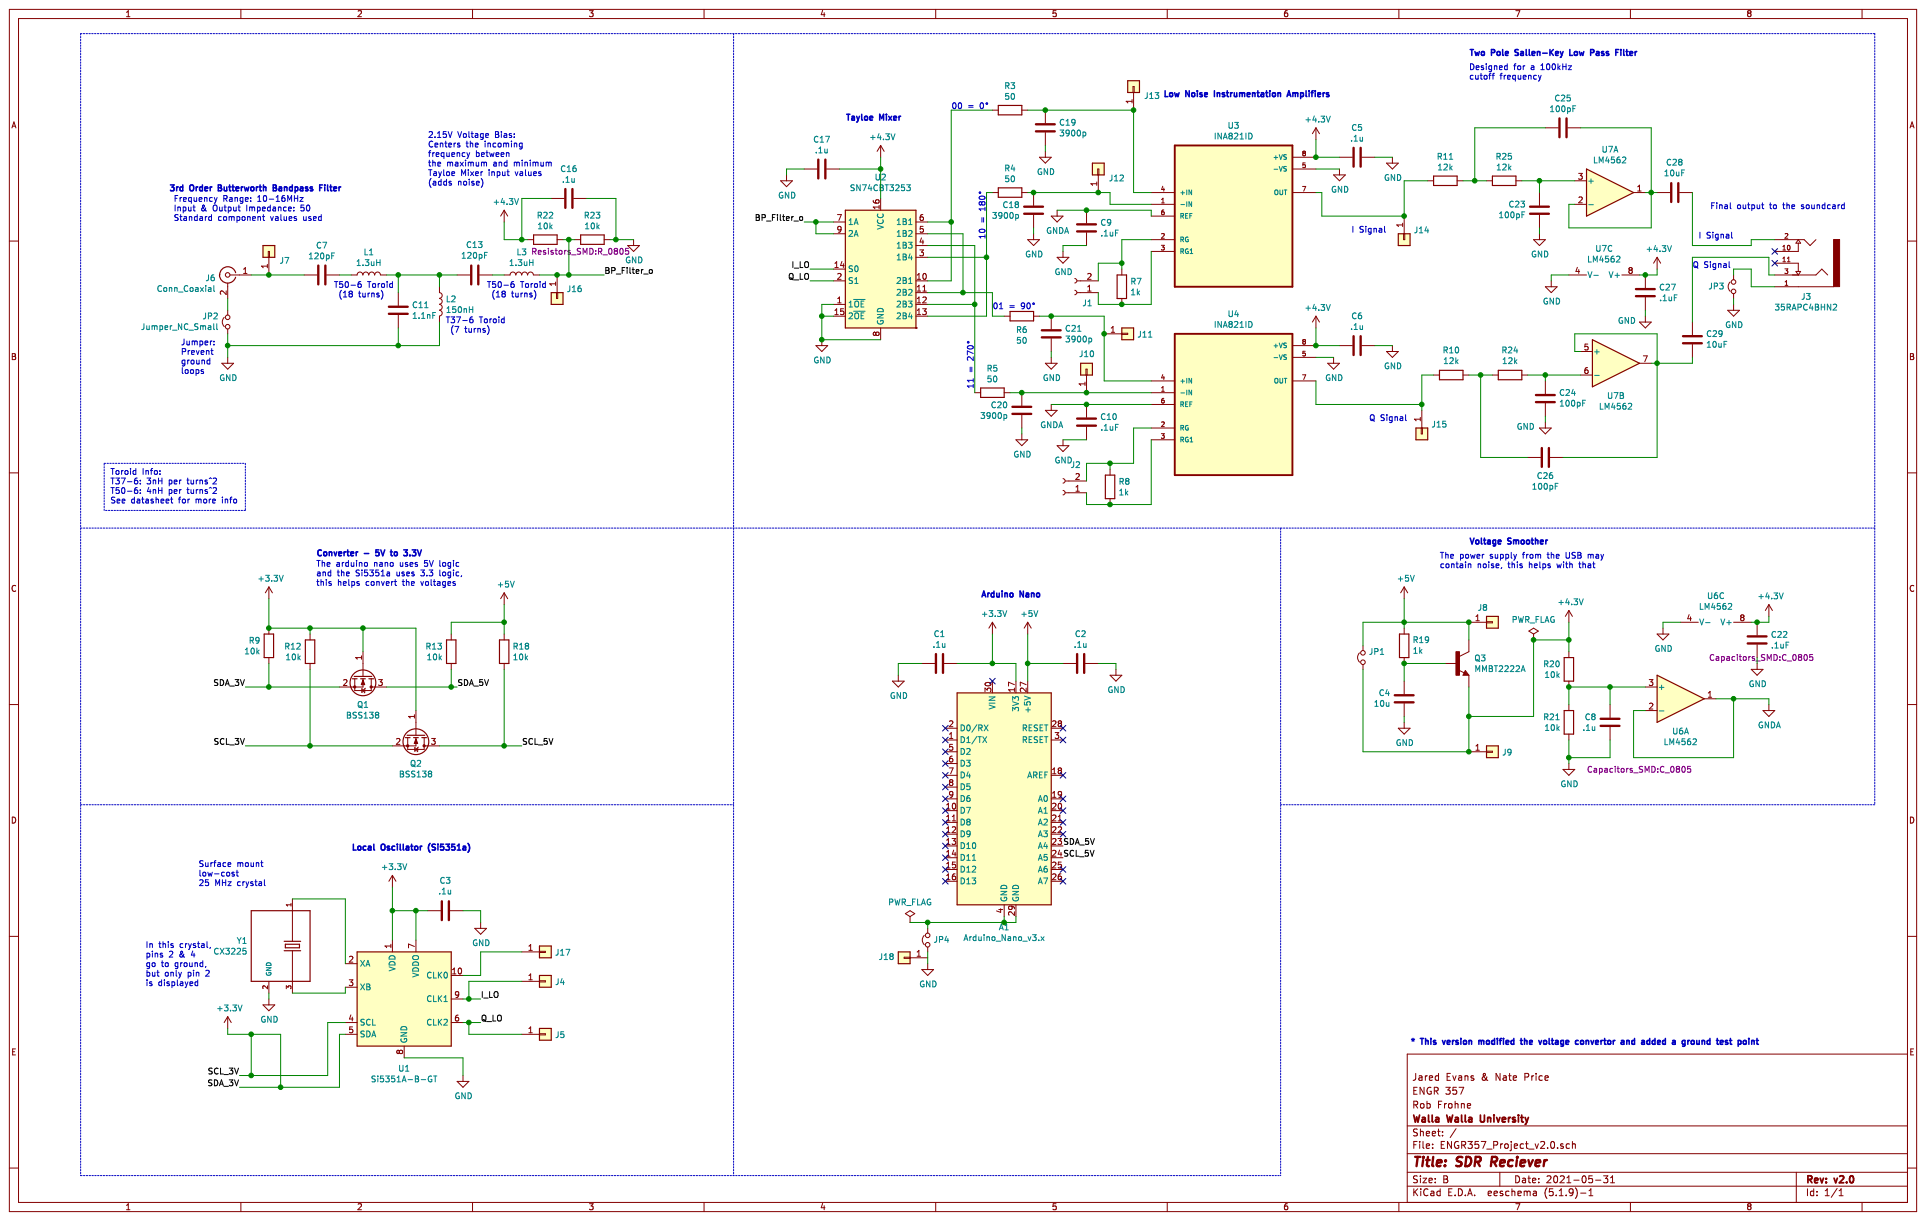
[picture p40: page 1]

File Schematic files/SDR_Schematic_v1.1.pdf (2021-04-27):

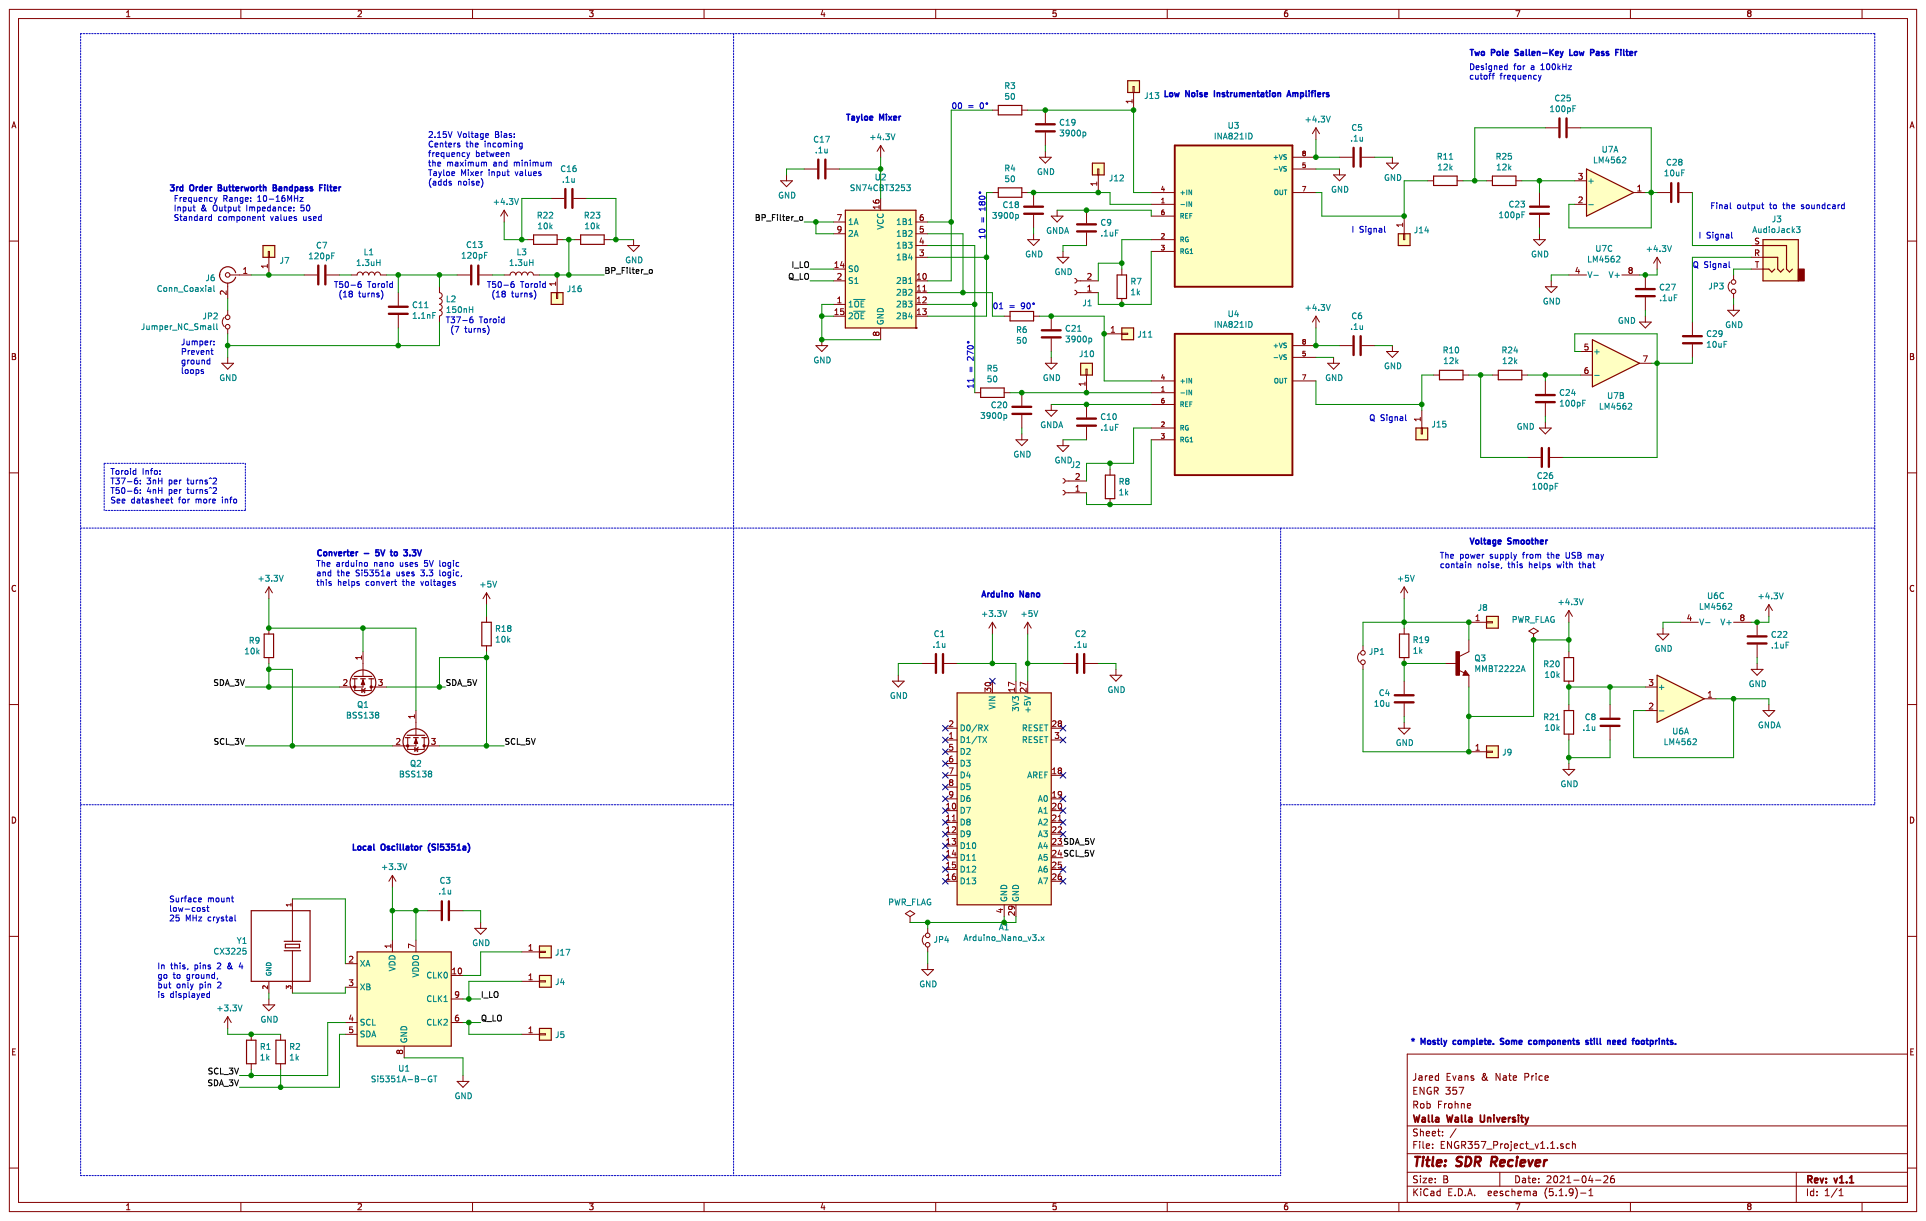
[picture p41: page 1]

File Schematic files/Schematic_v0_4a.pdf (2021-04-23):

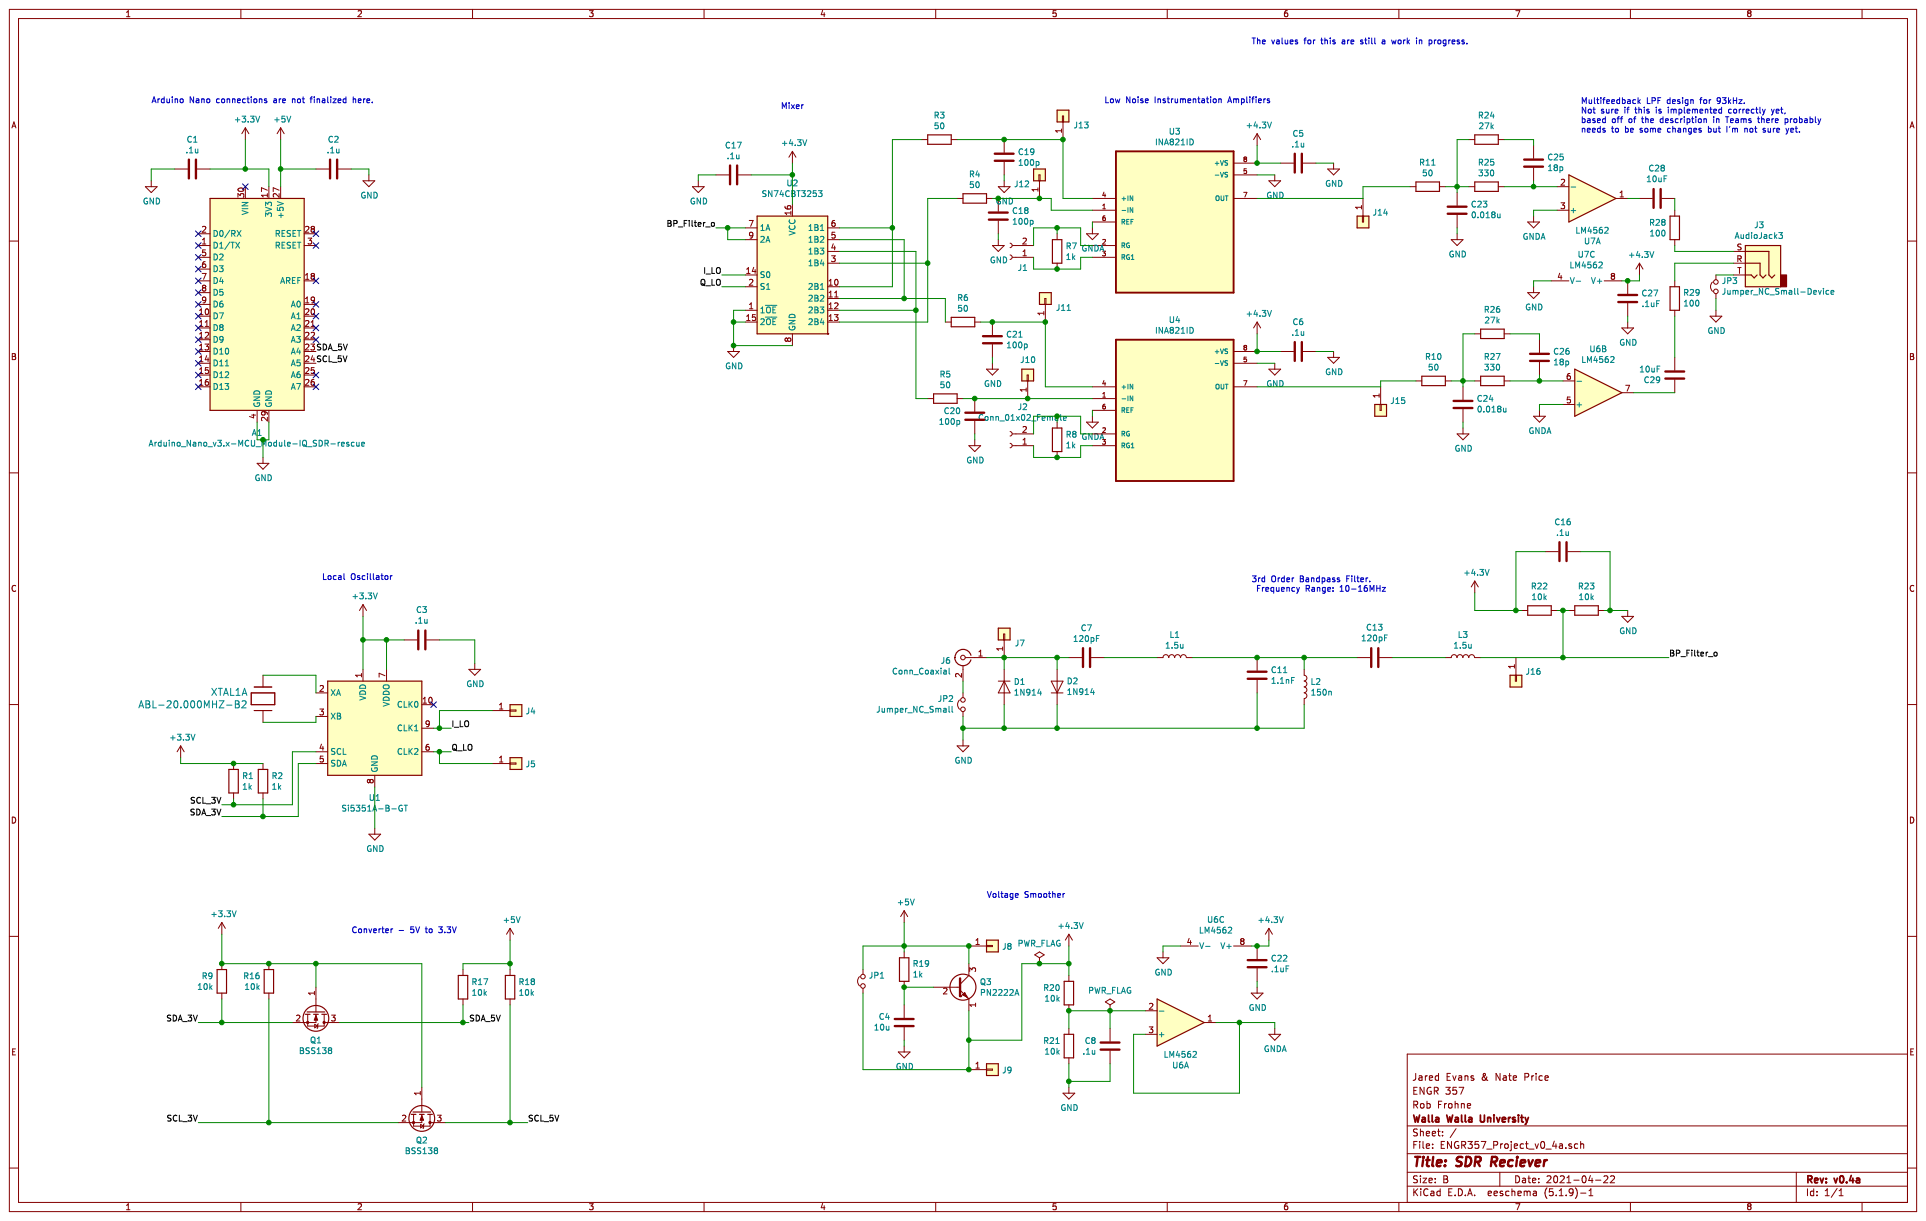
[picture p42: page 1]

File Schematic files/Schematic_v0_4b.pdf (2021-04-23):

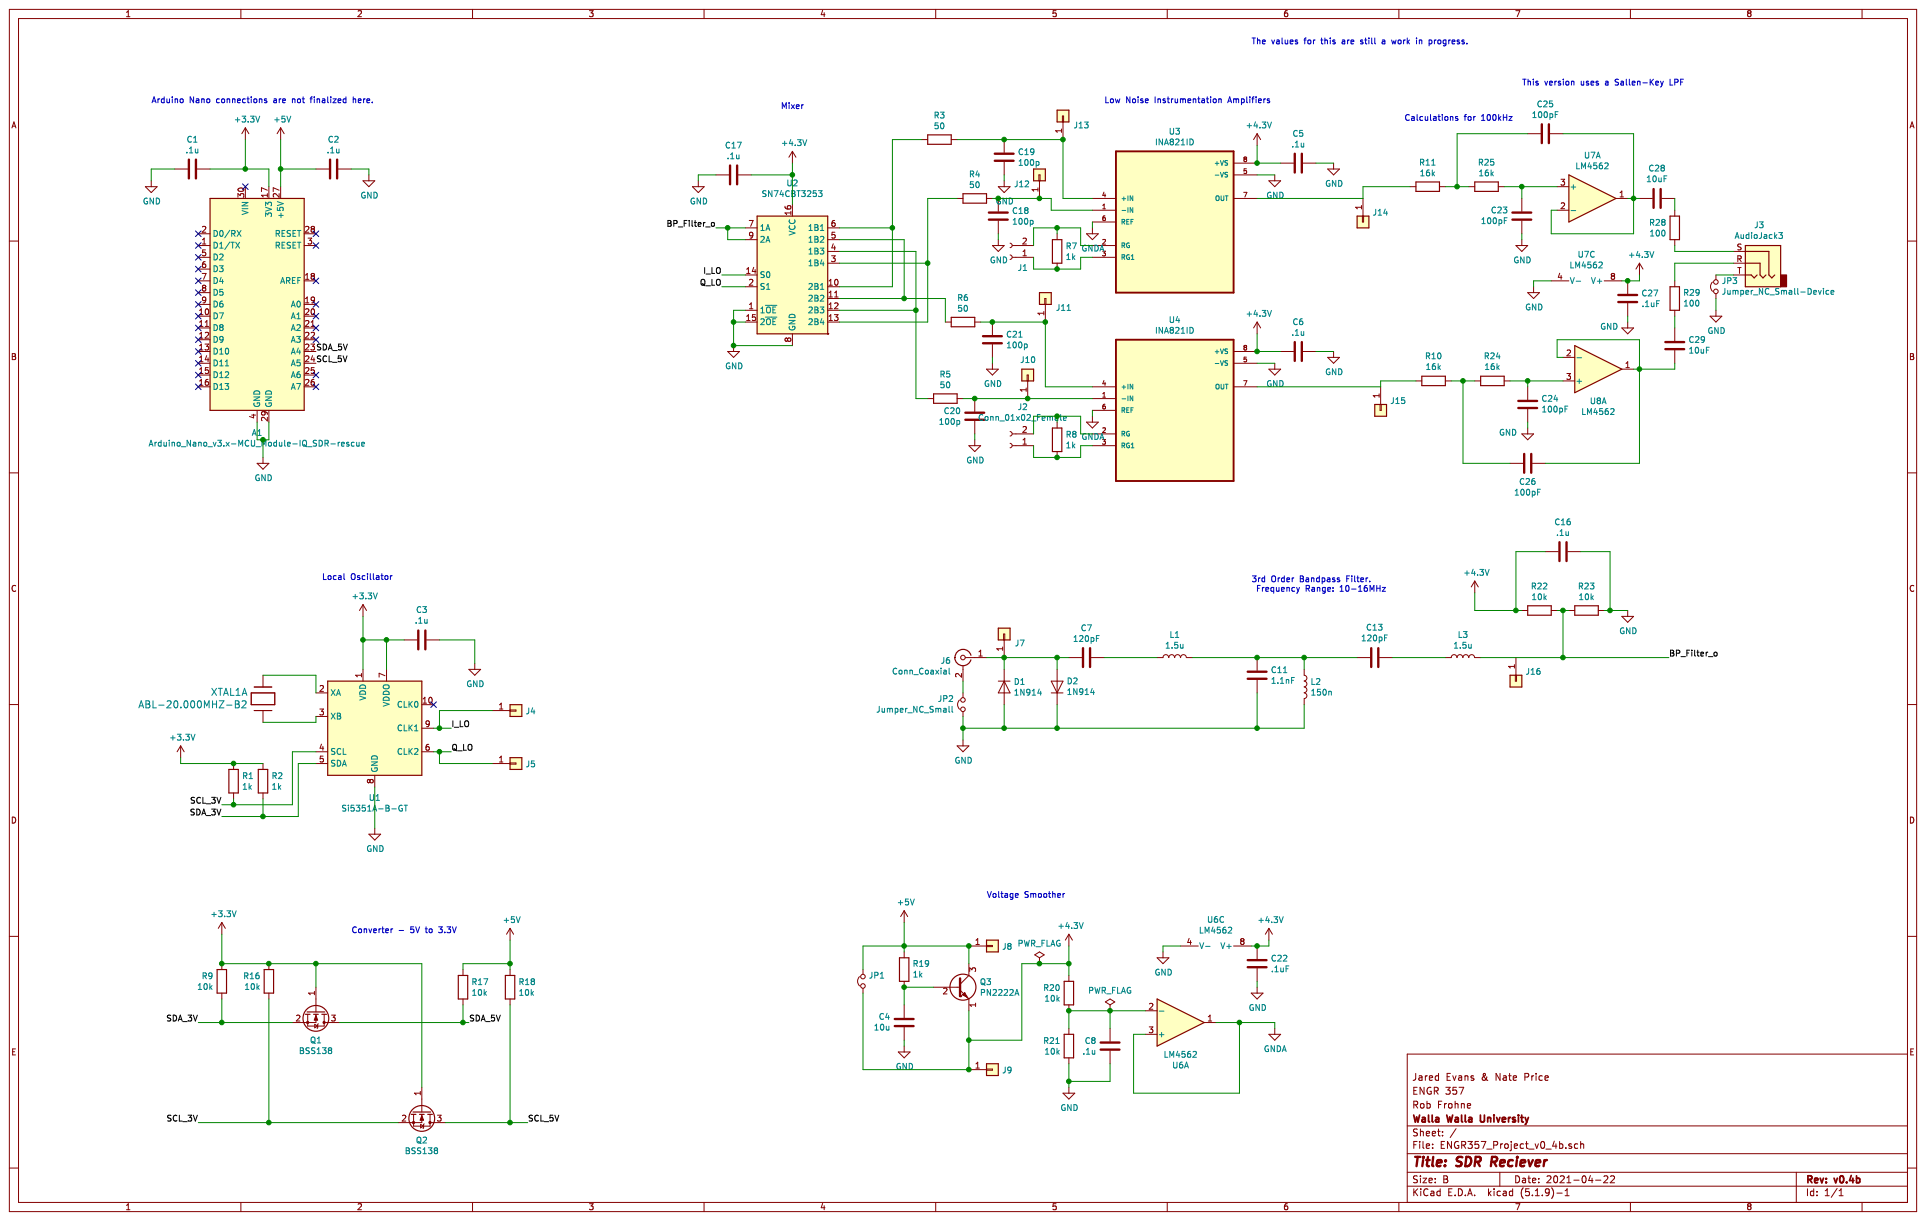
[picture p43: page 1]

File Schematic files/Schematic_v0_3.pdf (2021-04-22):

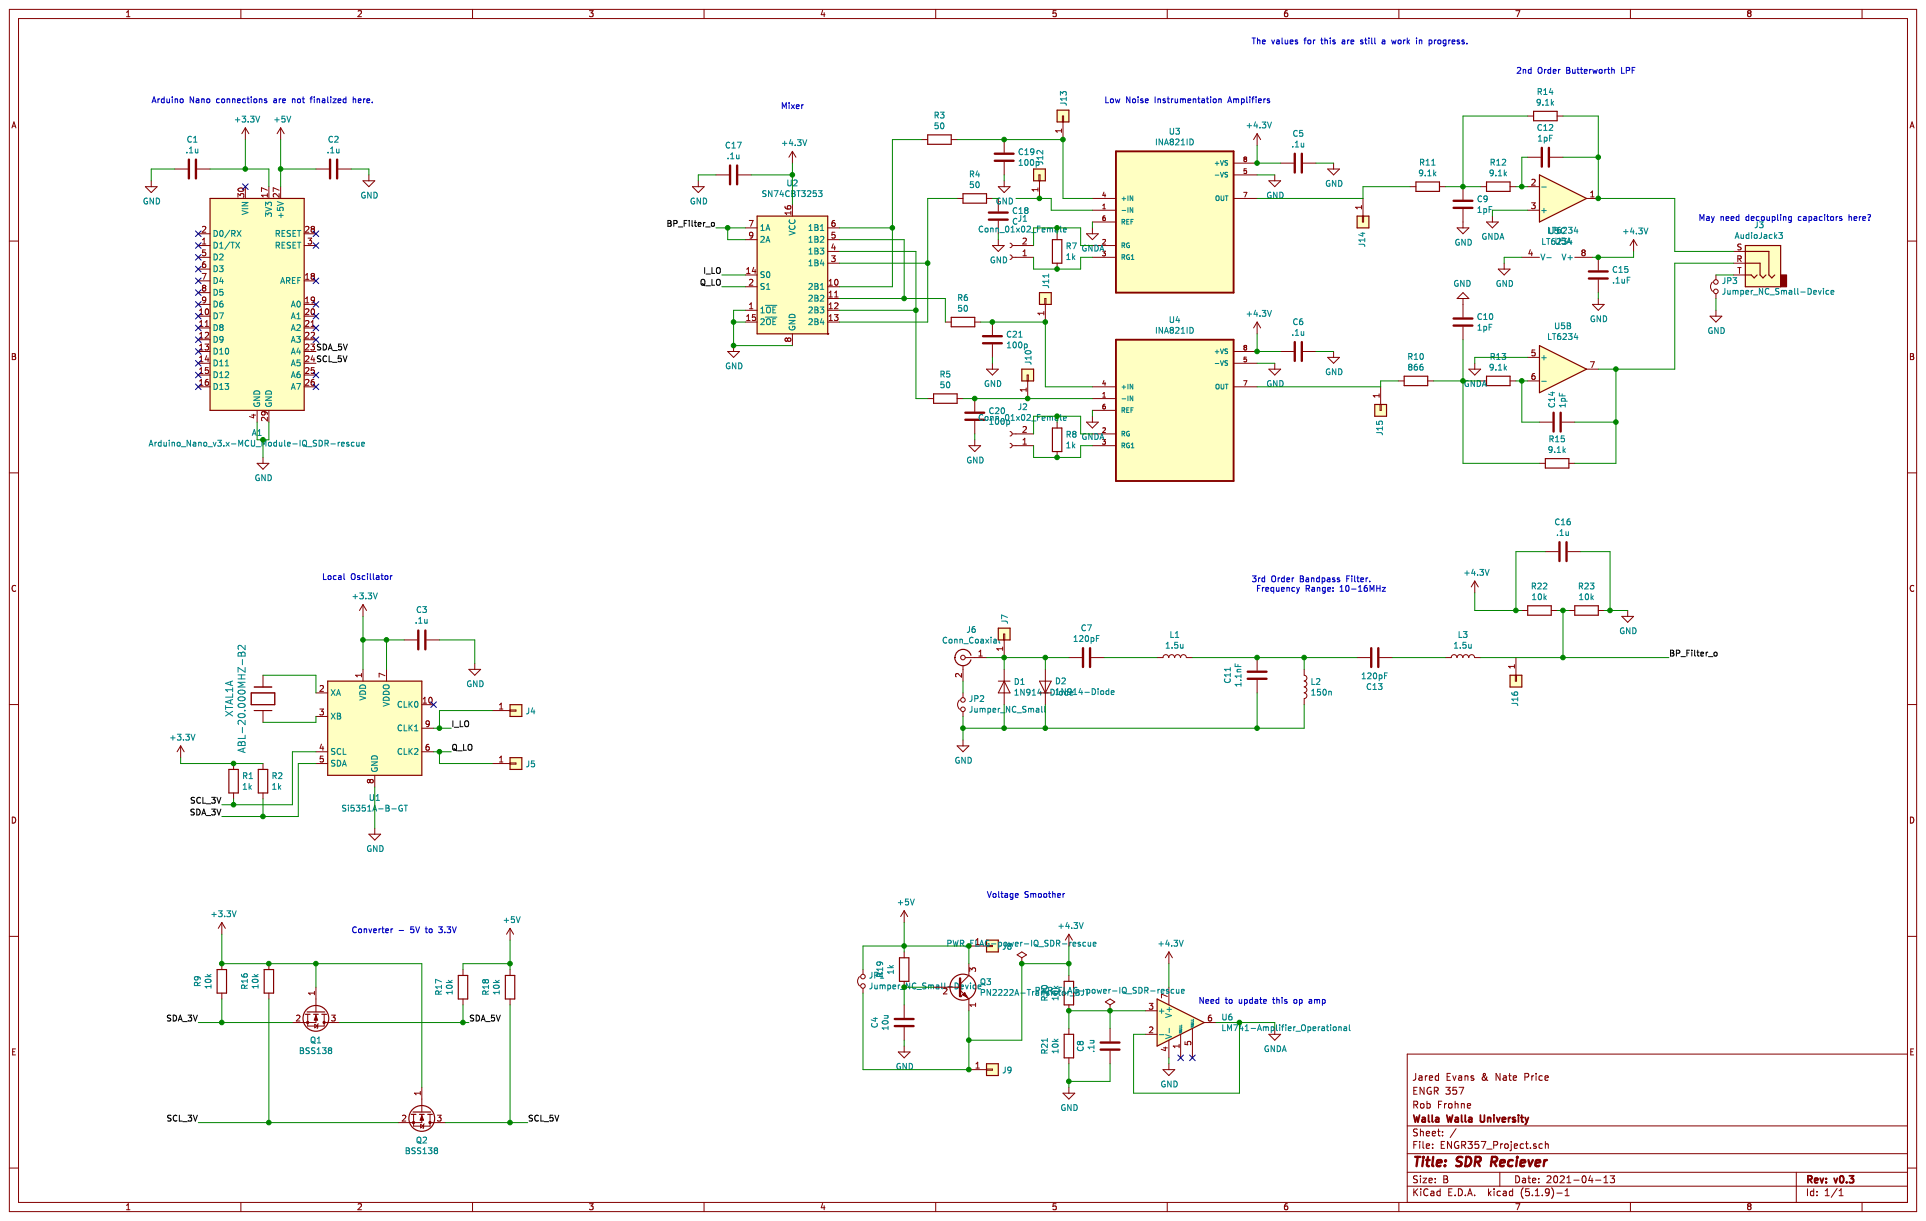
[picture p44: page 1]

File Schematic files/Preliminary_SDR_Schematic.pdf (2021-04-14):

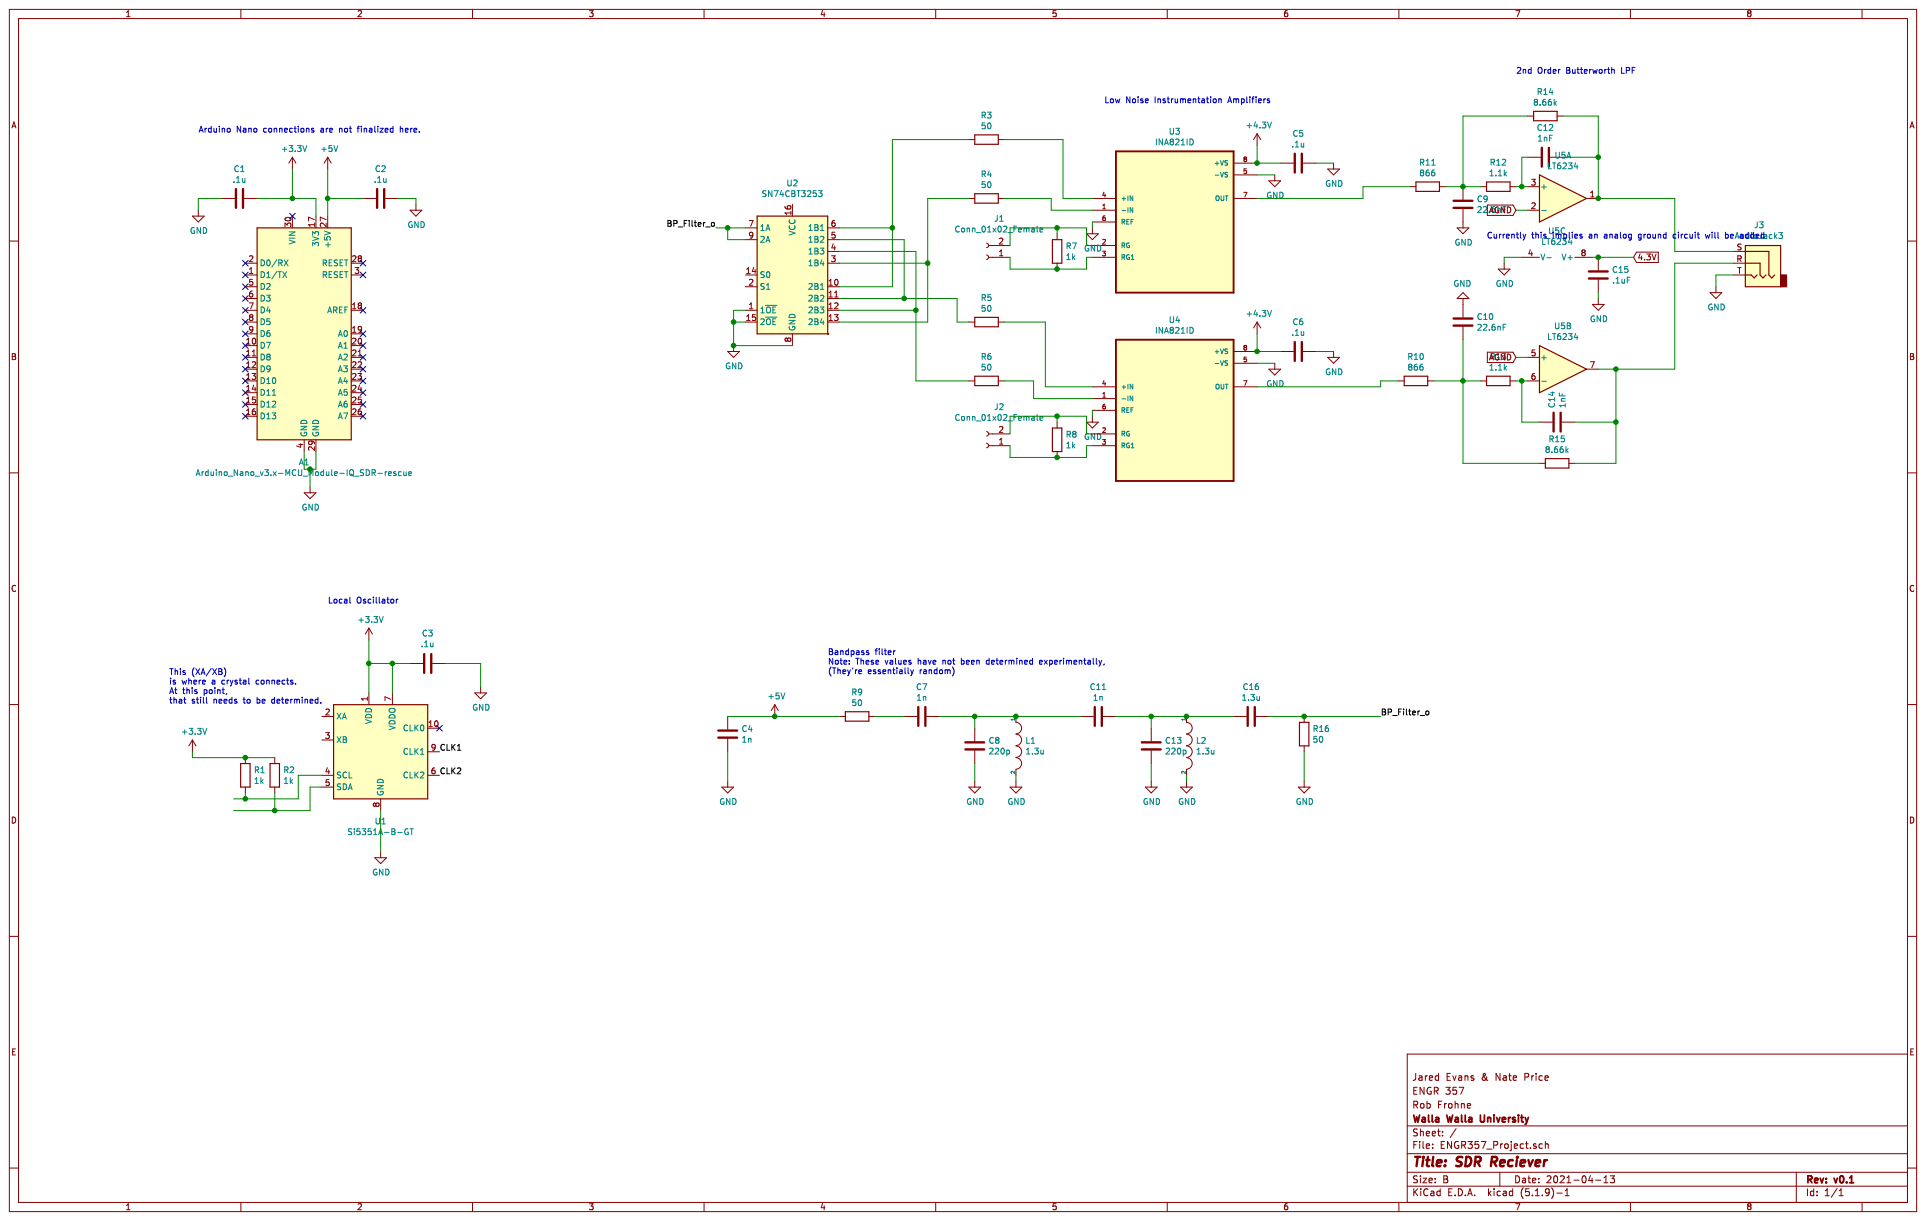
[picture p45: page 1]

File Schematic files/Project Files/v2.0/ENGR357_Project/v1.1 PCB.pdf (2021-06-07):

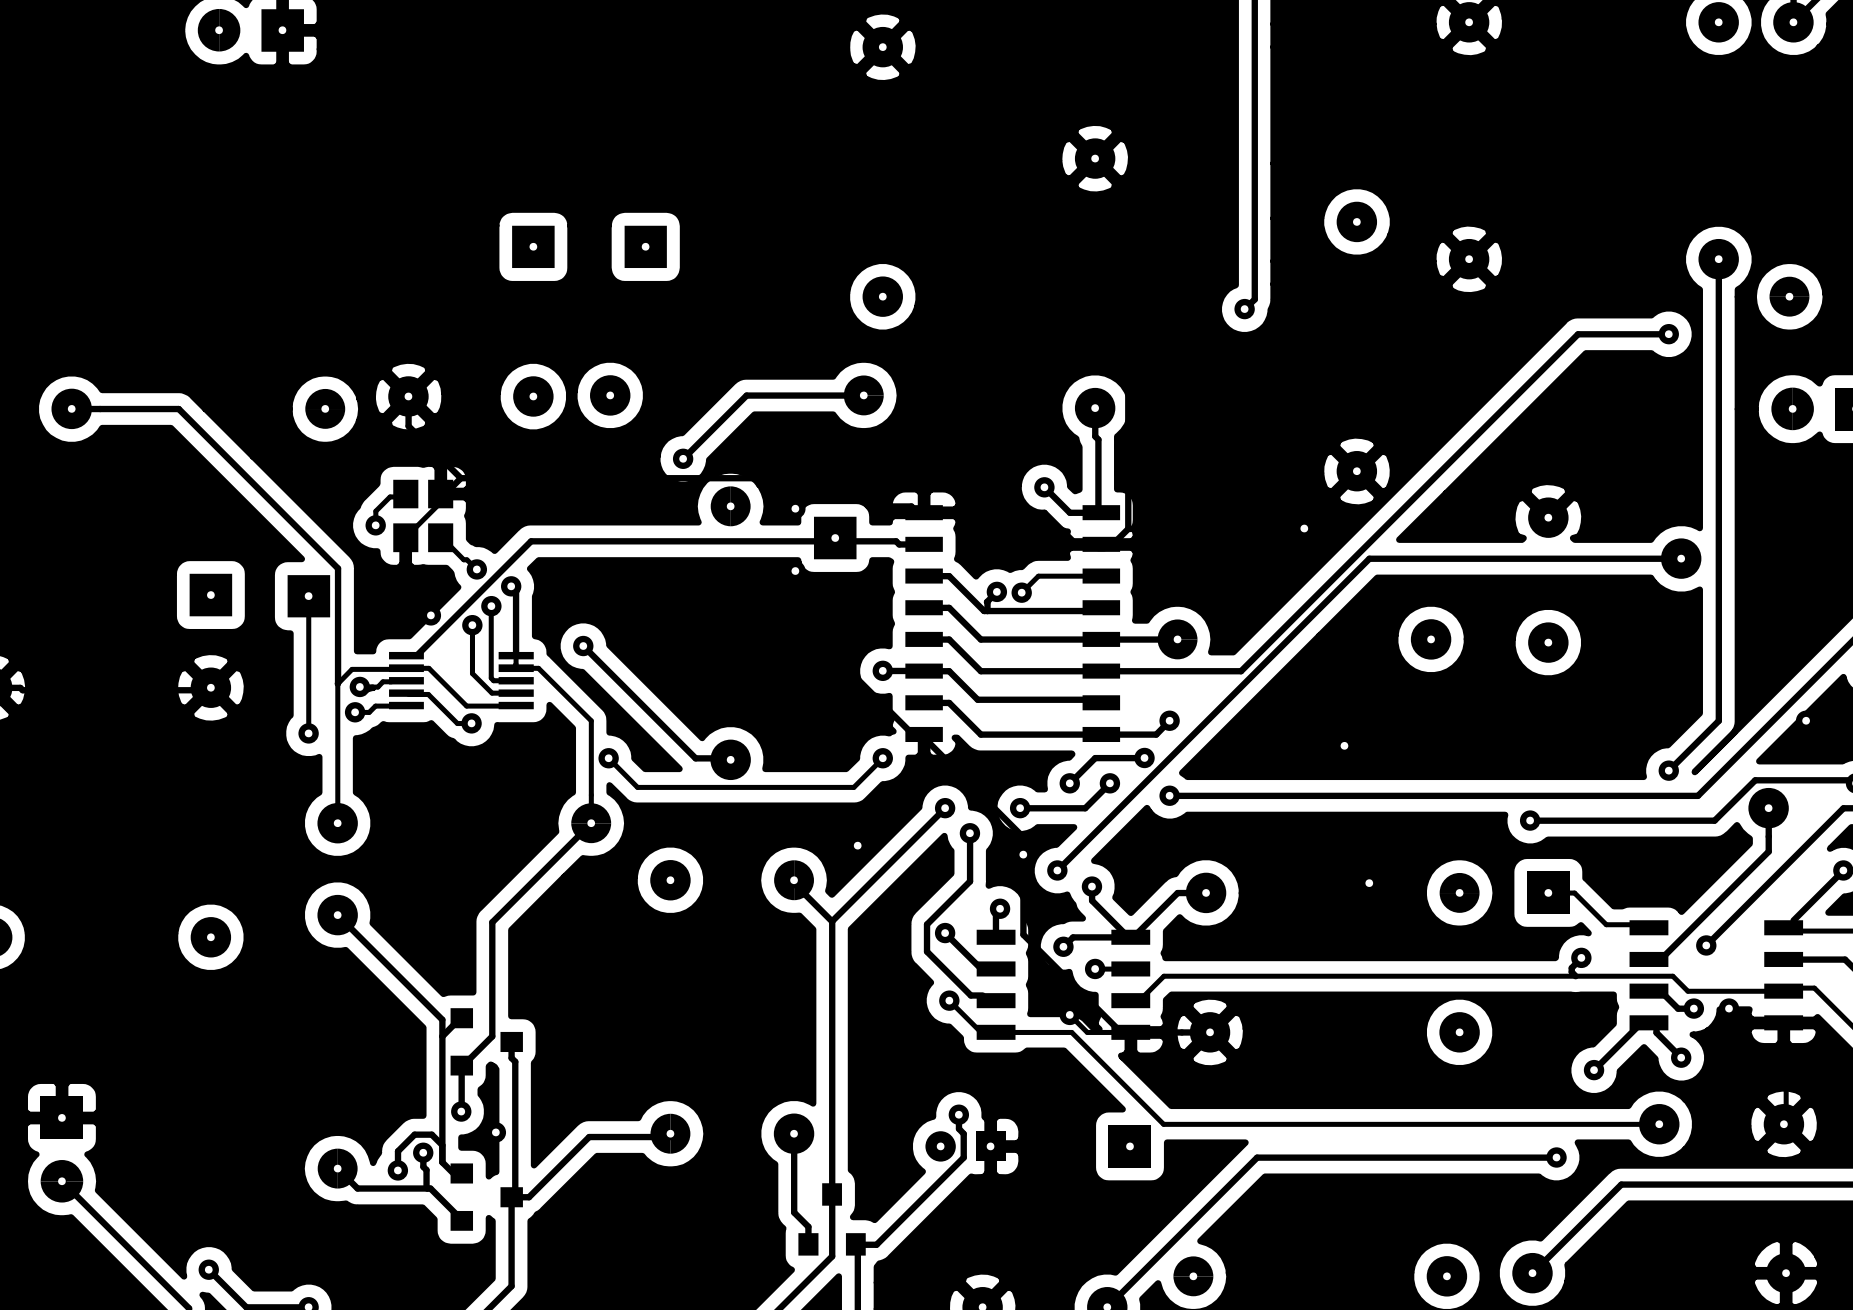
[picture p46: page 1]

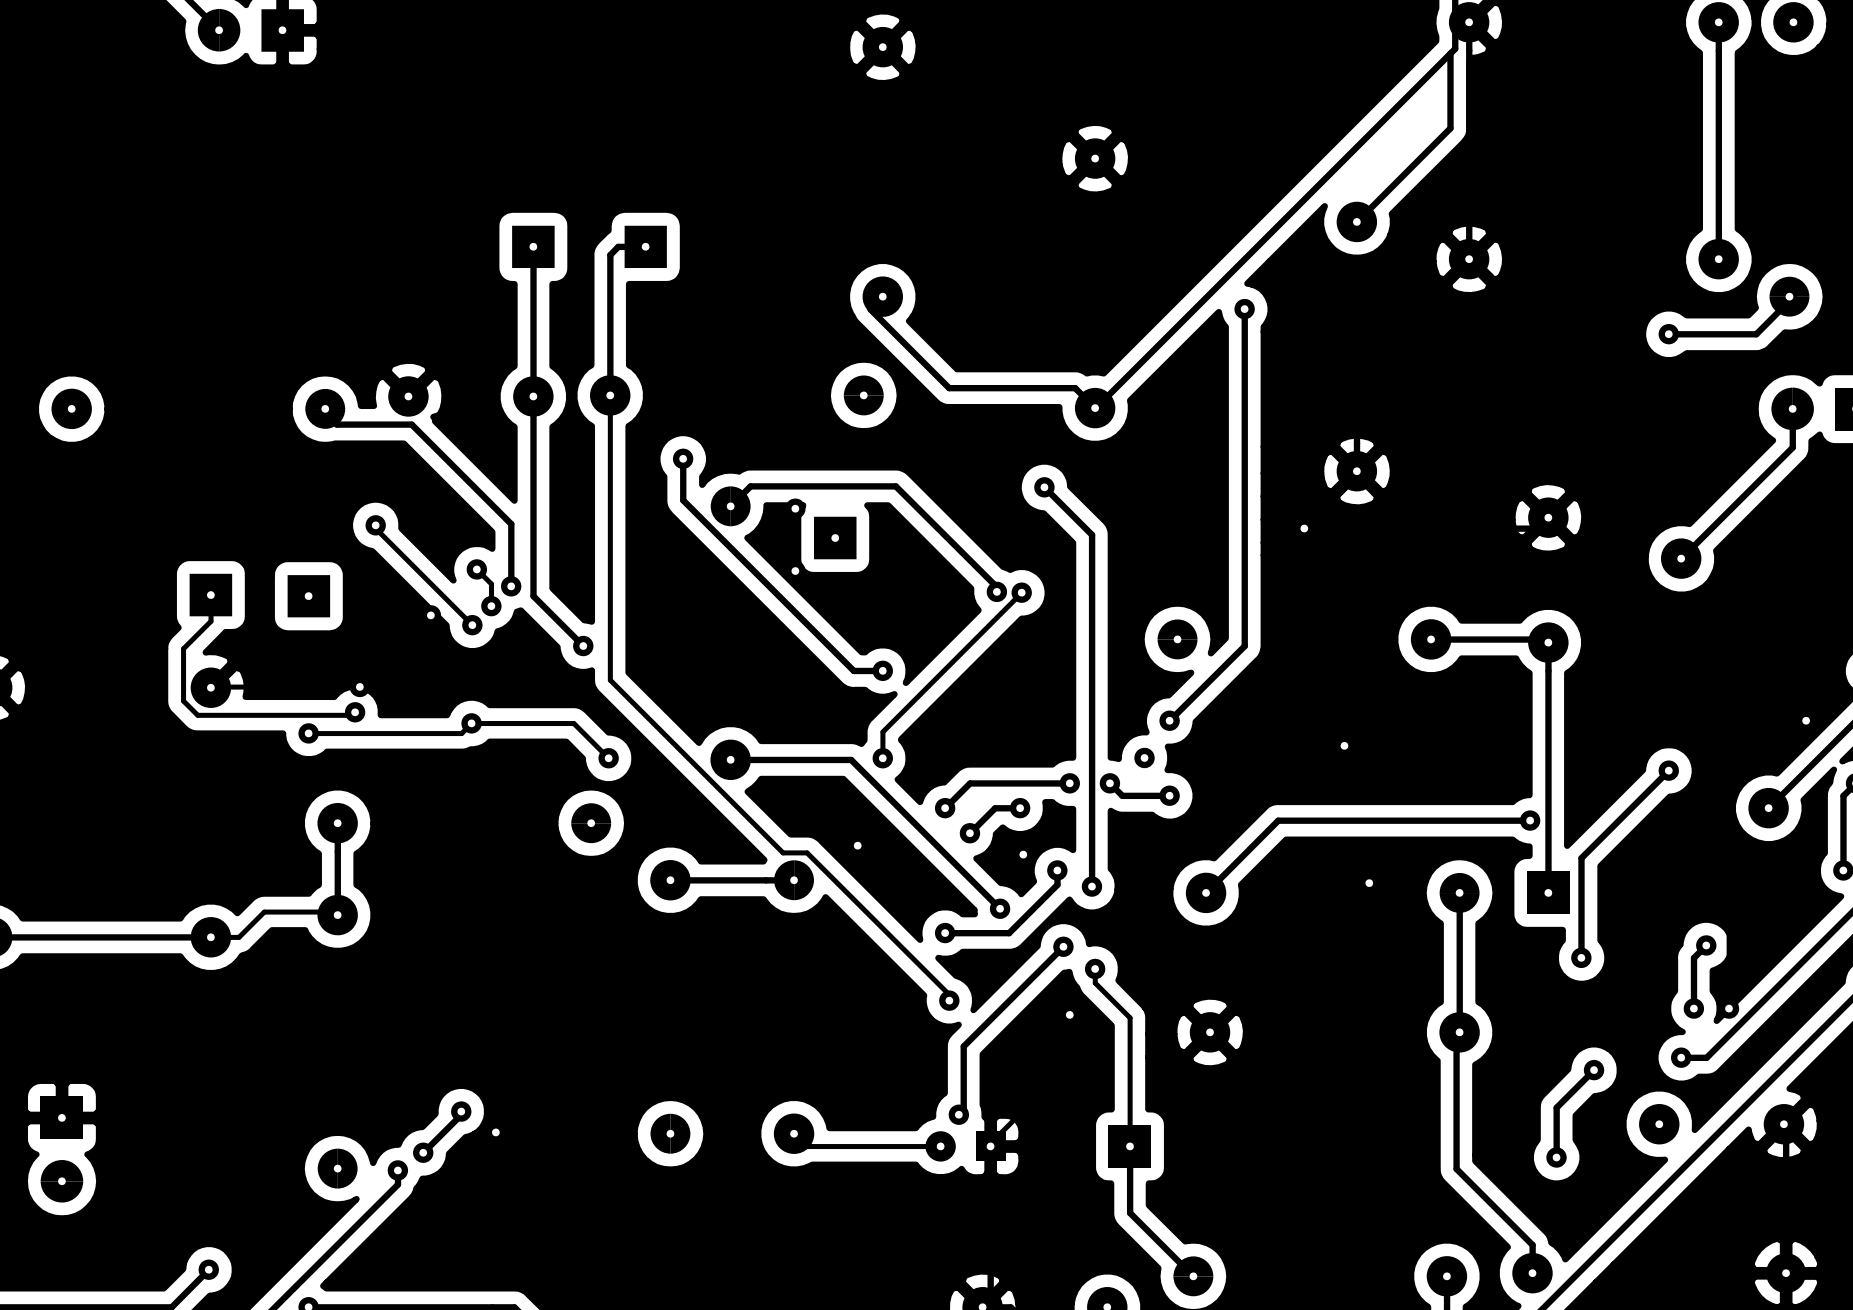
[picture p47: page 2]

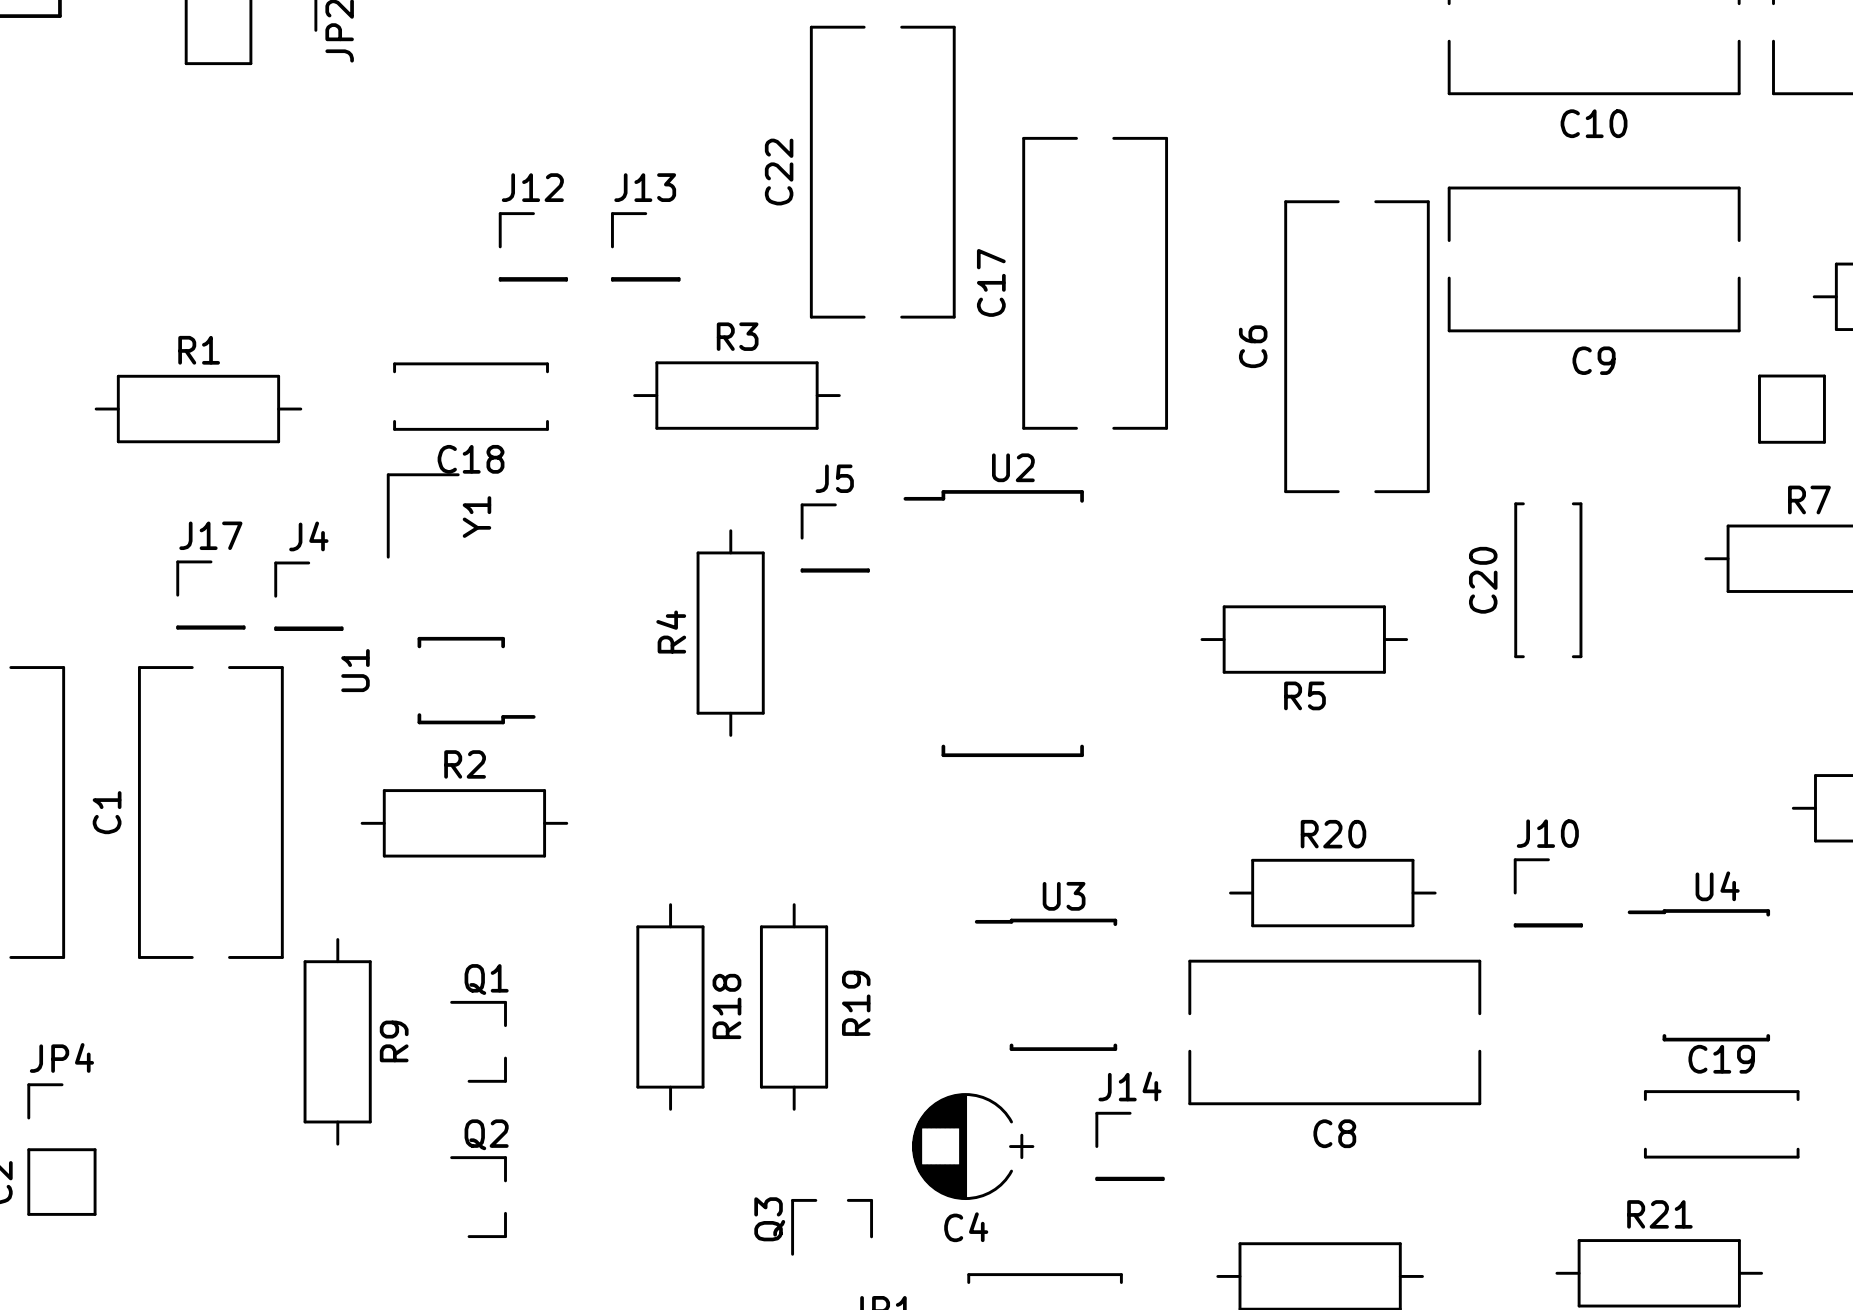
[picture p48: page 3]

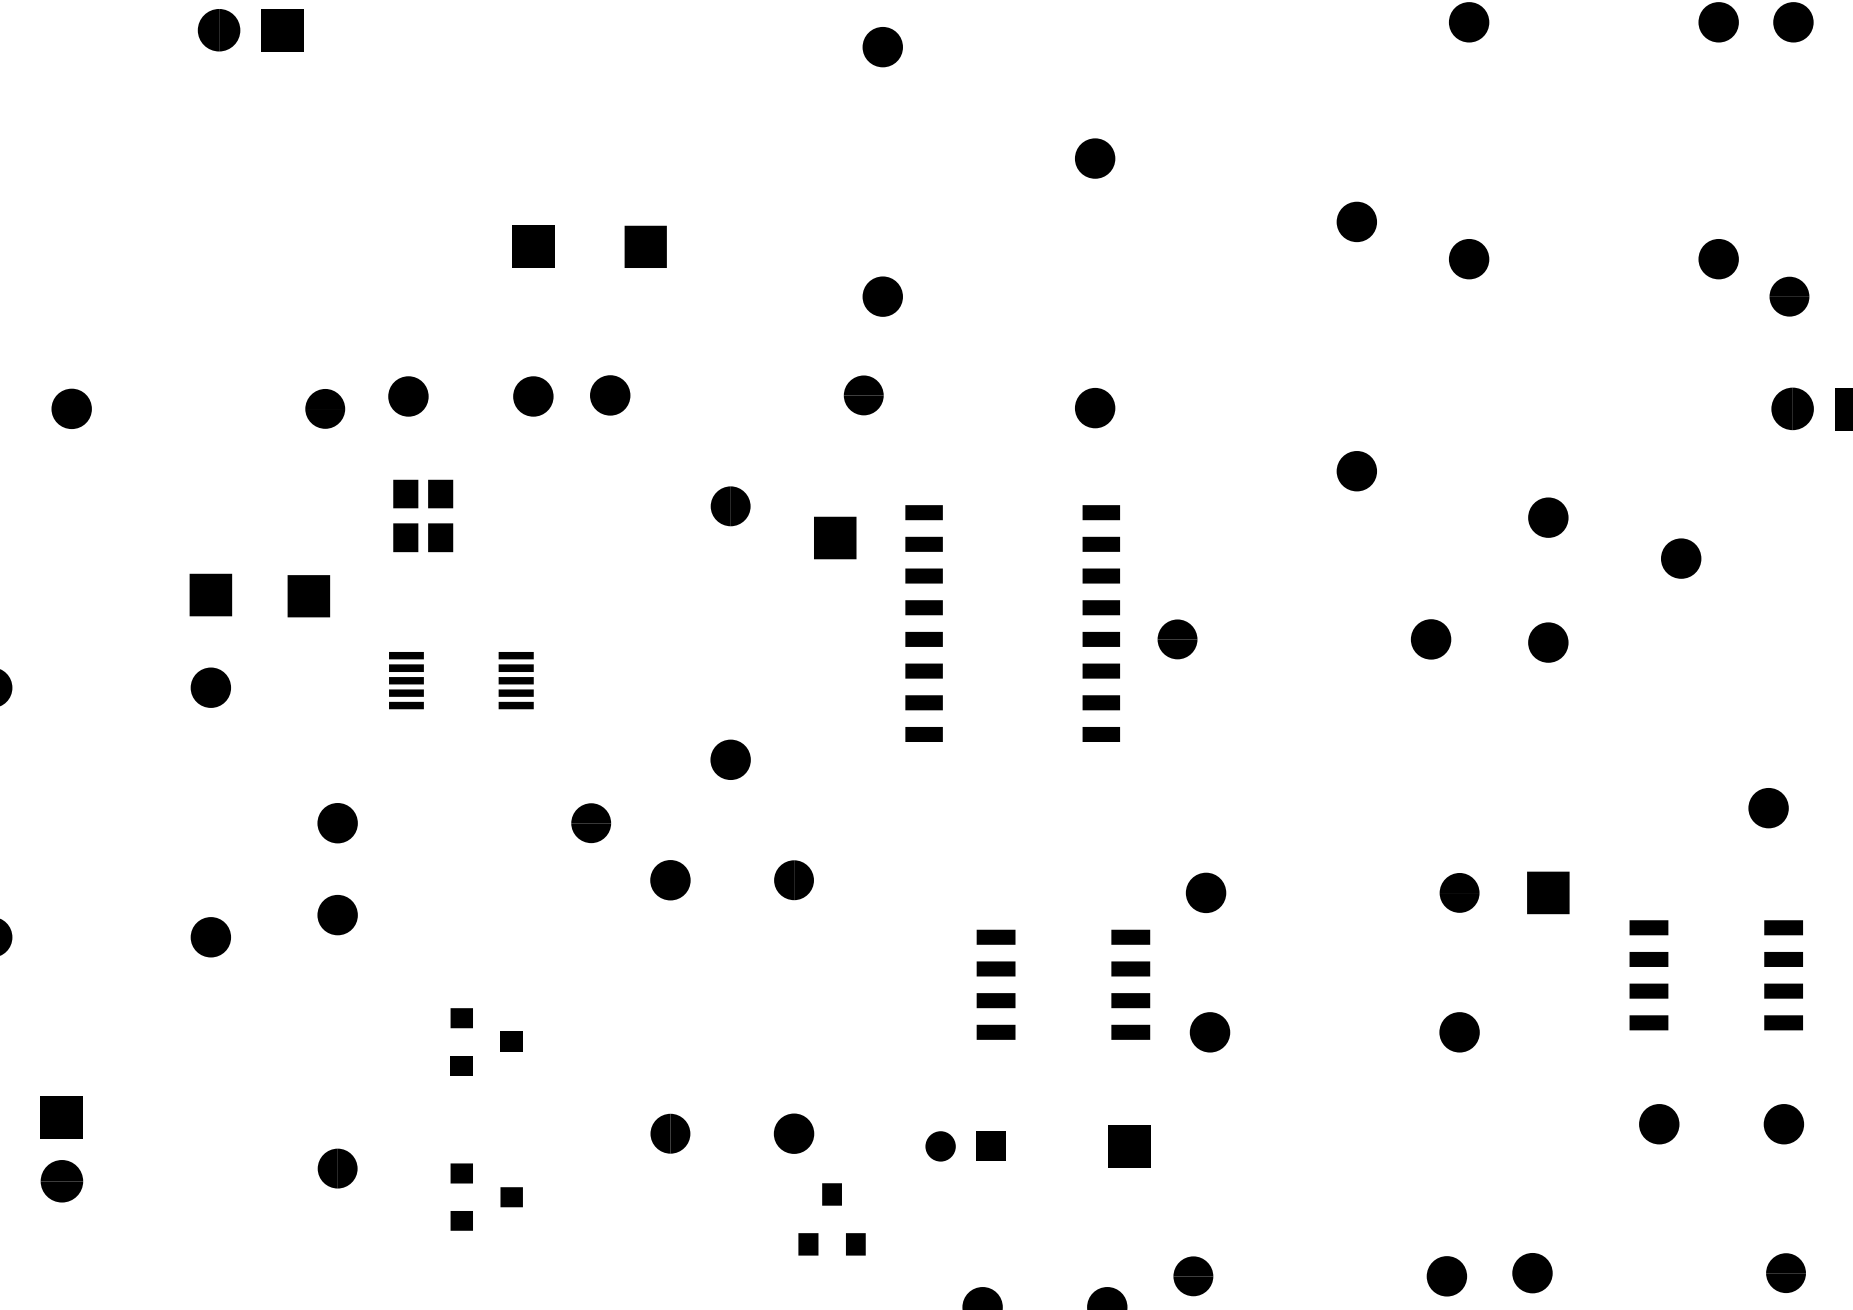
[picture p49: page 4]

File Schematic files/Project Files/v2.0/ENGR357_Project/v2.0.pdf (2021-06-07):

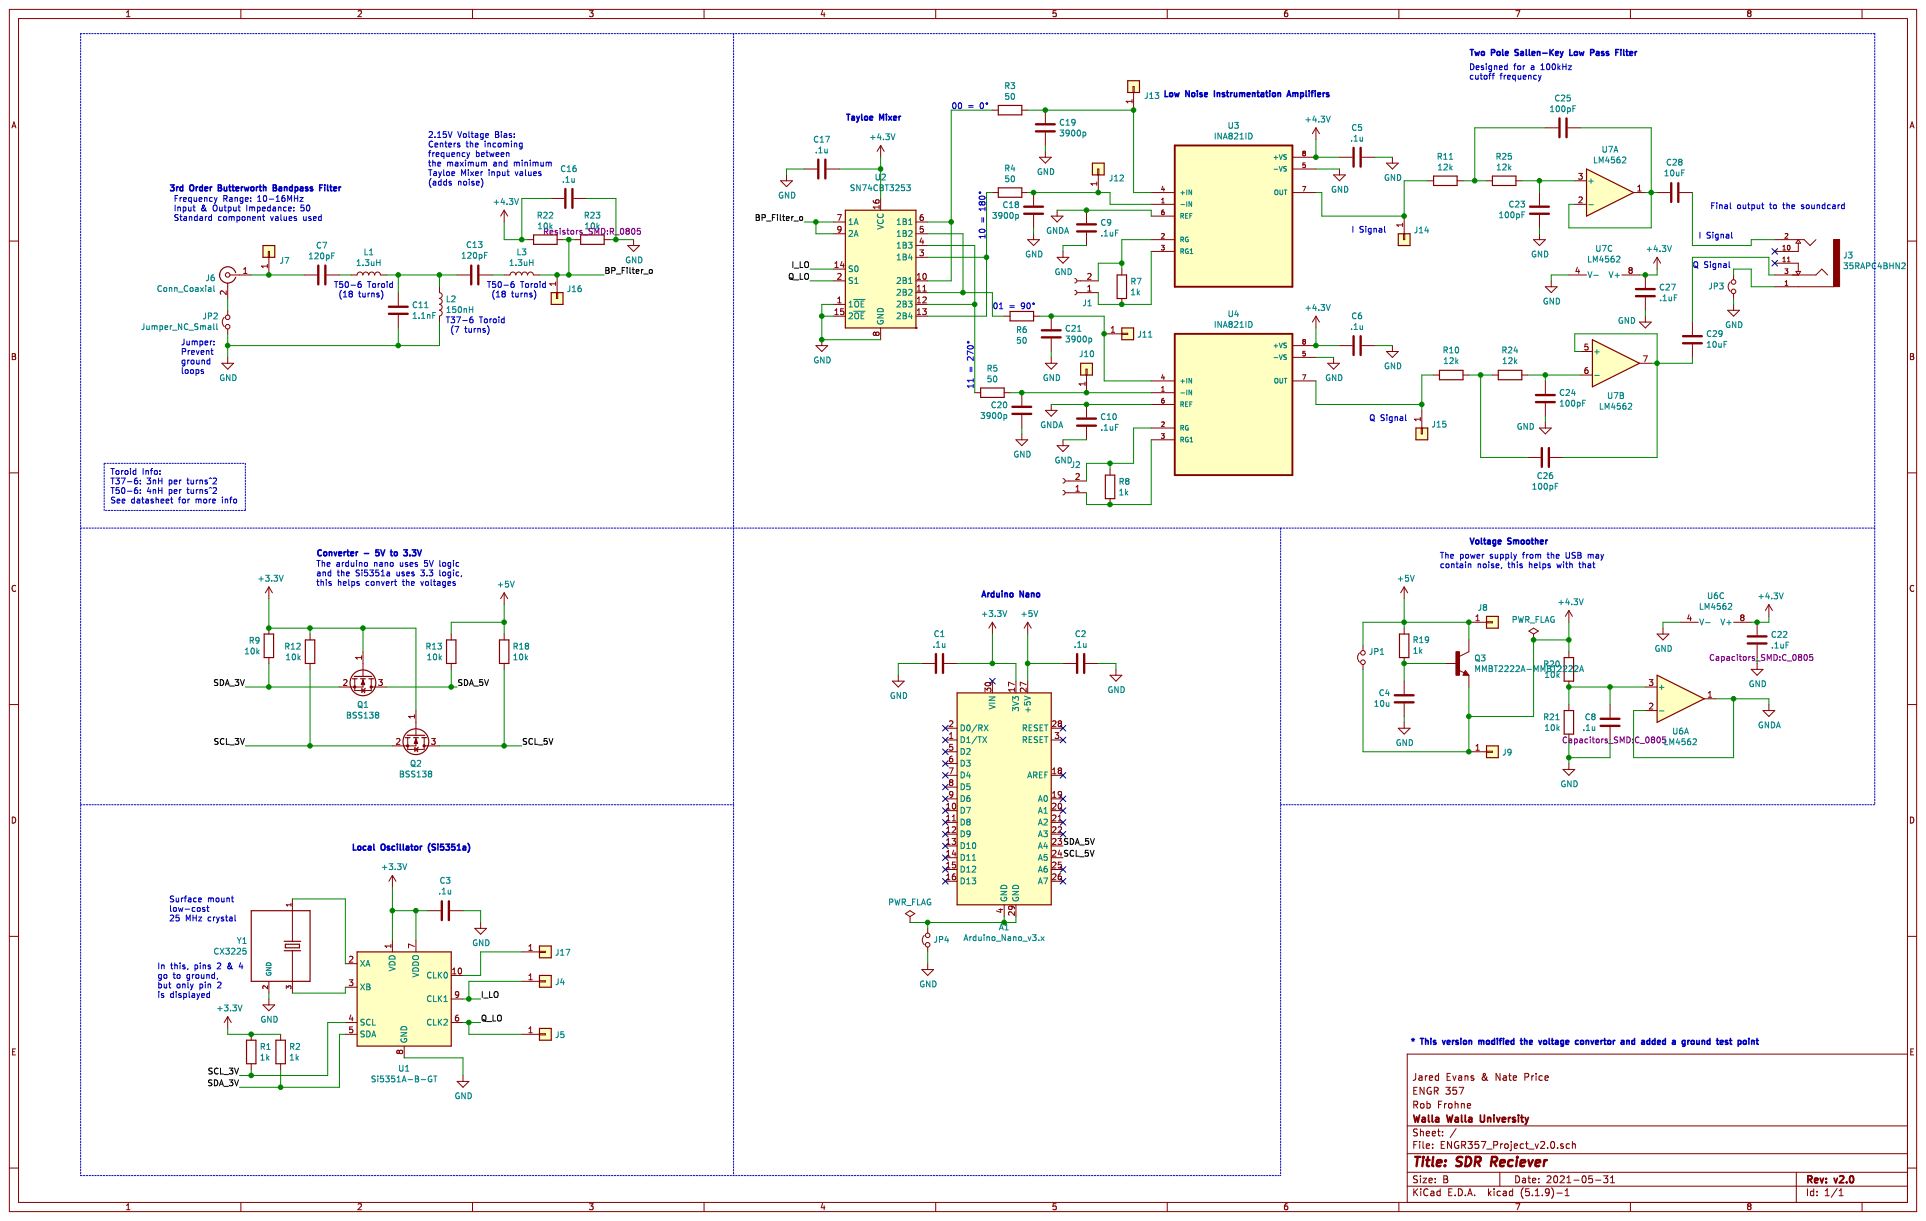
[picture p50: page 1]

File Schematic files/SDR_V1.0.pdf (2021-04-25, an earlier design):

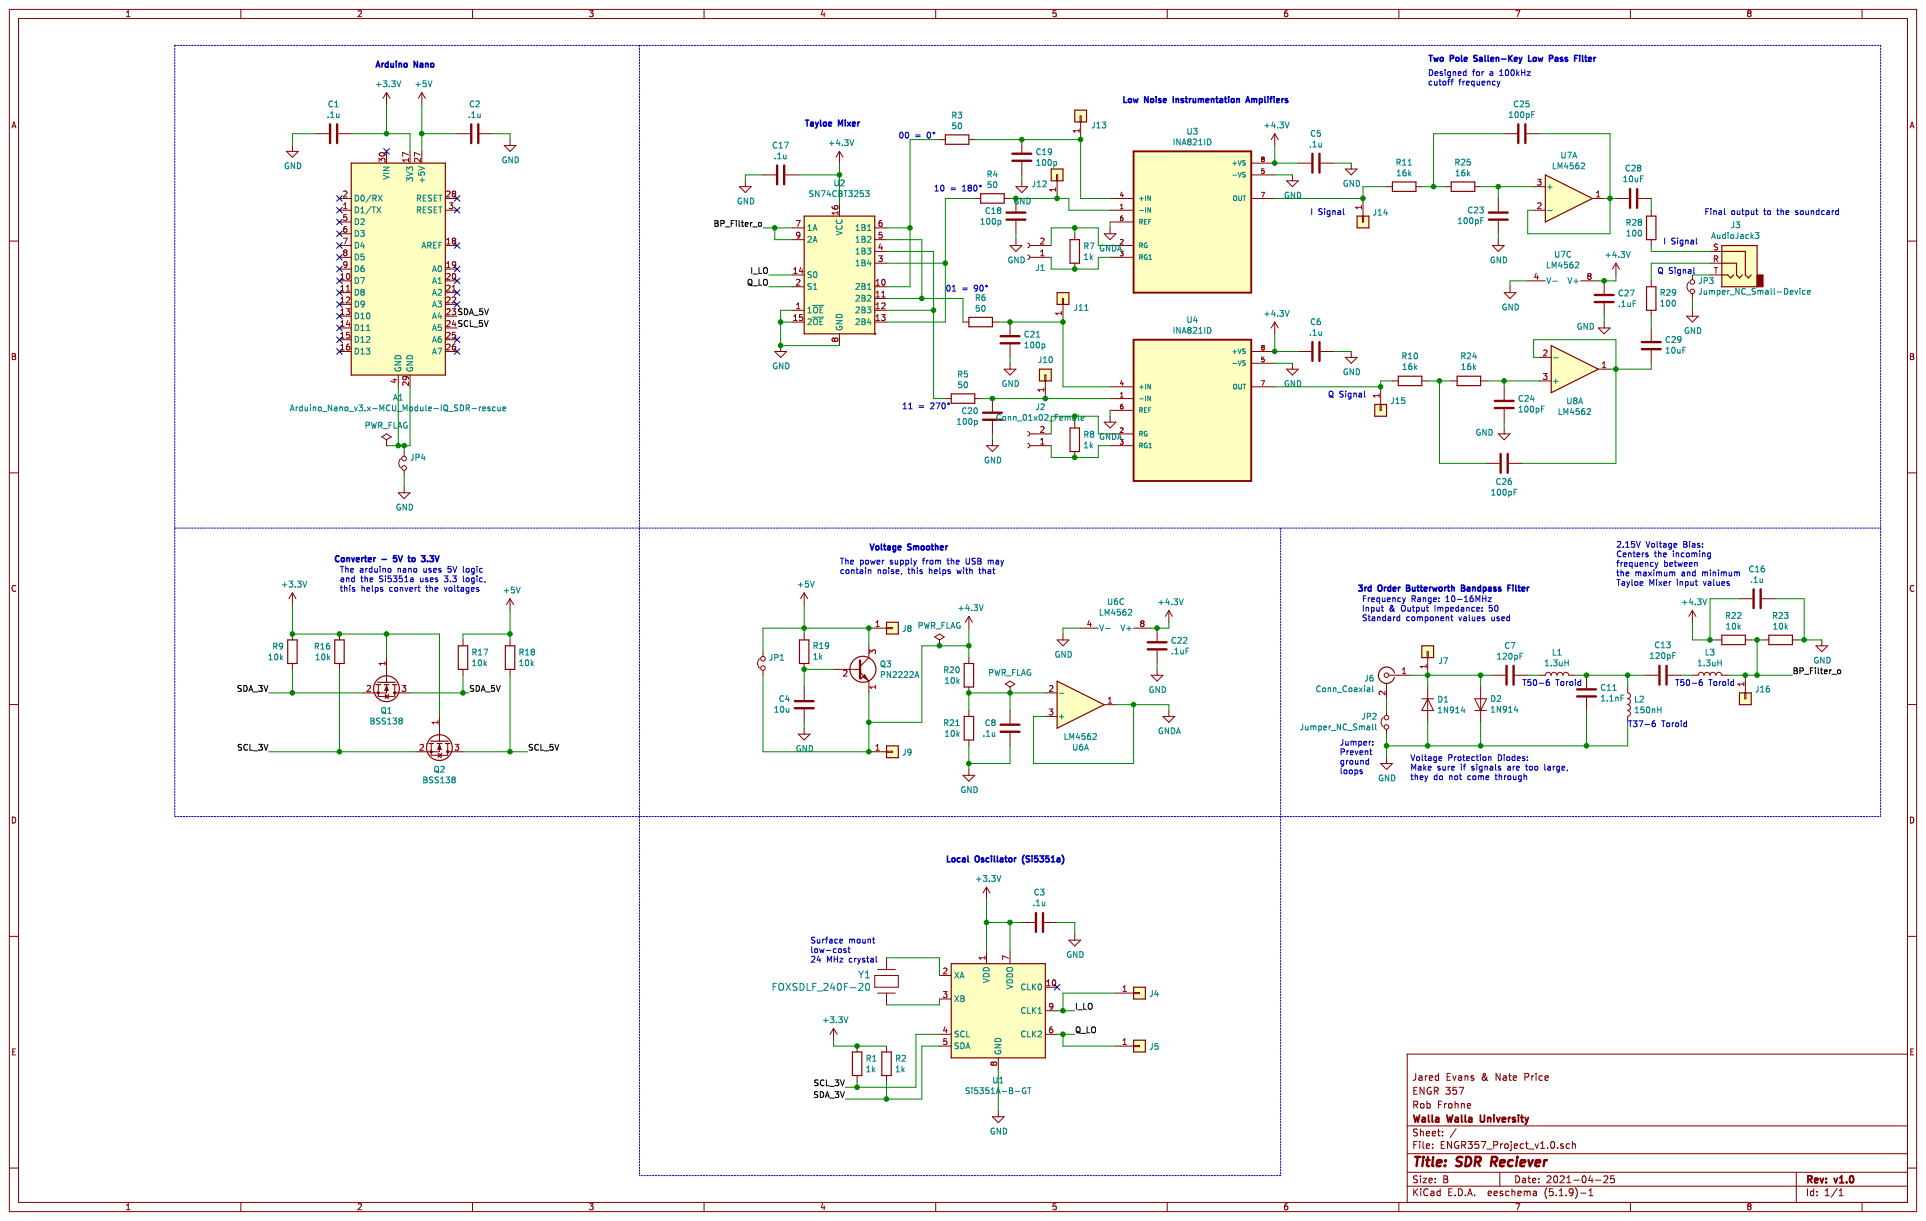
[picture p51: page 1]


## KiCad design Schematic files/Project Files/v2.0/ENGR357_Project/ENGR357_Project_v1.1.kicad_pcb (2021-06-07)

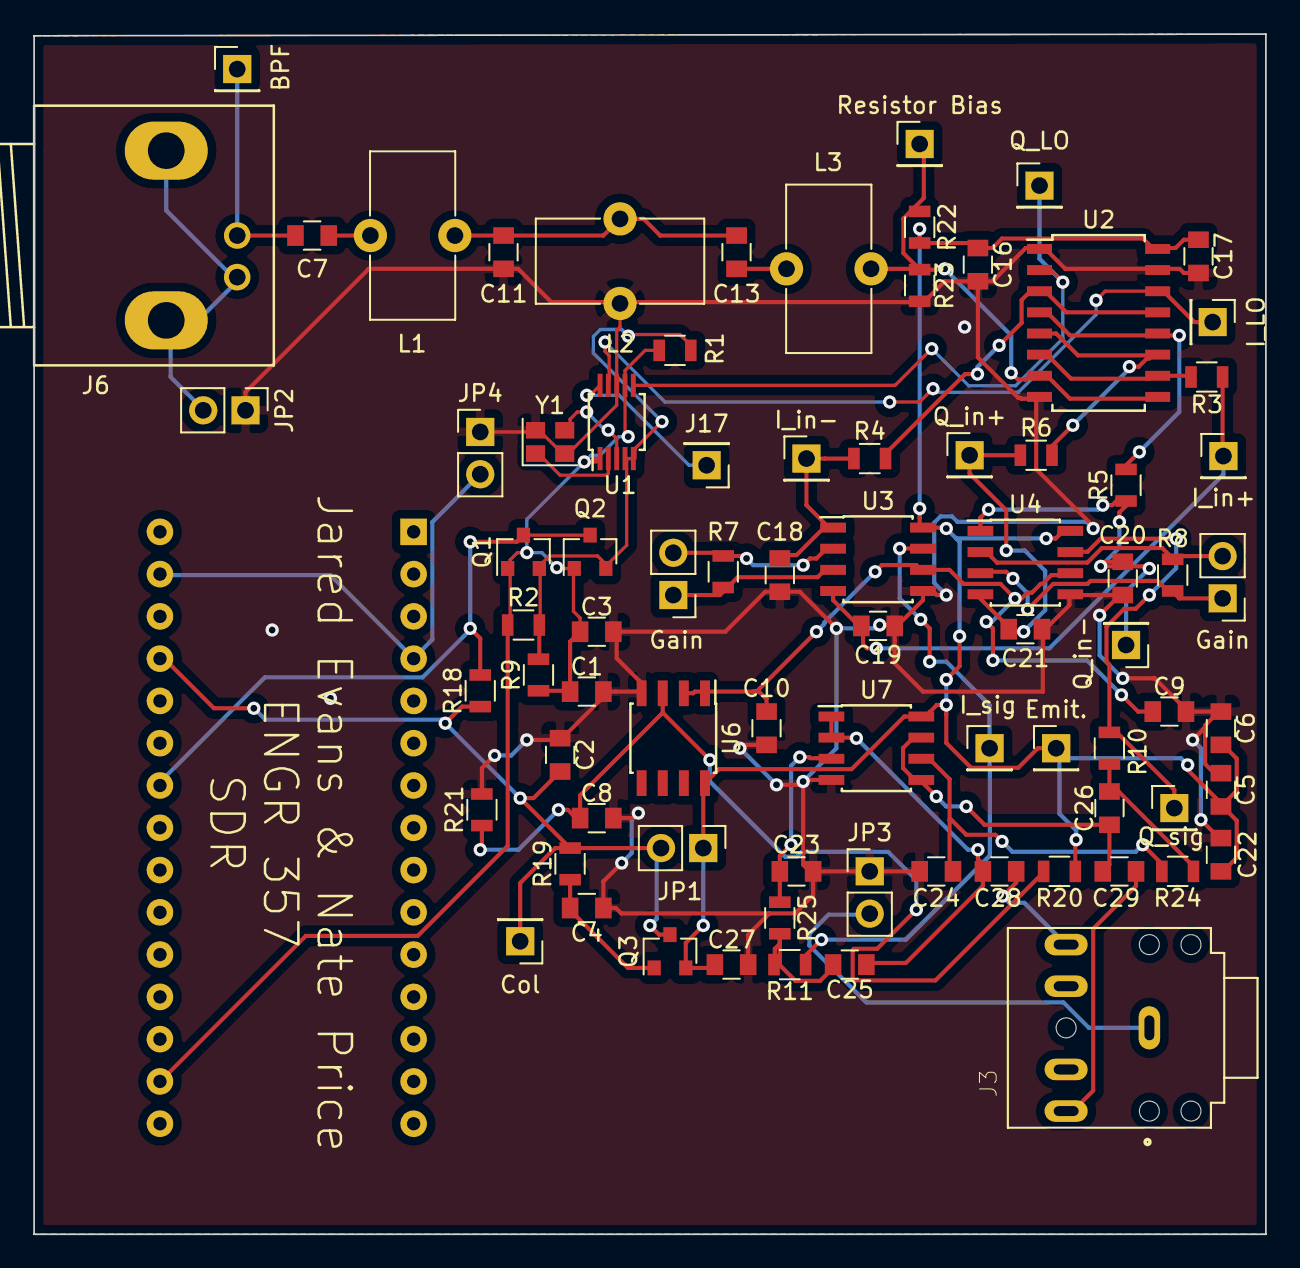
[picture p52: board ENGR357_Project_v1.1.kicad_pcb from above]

Board: 2 copper layers, 74.0 x 72.1 mm, 80 parts (1 on the bottom side), 44 nets.

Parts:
A1: Arduino_Nano_v3.x; Arduino_Nano
BPF: IQ_SDR-rescue_Conn_01x01-Connector_Generic-IQ_SDR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; Pin_Header_Straight_1x01_Pitch2.54mm
C1, C2, C3, C5, C6, C8, C16, C17: .1u; C_0805
C4: 10u; C_0805
C7, C13: 120pF; C_0805
C9, C10, C22, C27: .1uF; C_0805
C11: 1.1nF; C_0805
C18, C19, C20, C21: 3900p; C_0805
C23, C24, C25, C26: 100pF; C_0805
C28, C29: 10uF; C_0805
Col: IQ_SDR-rescue_Conn_01x01-Connector_Generic-IQ_SDR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; Pin_Header_Straight_1x01_Pitch2.54mm
Emit.: IQ_SDR-rescue_Conn_01x01-Connector_Generic-IQ_SDR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; Pin_Header_Straight_1x01_Pitch2.54mm
Gain: Conn_01x02_Female; Pin_Header_Straight_1x02_Pitch2.54mm
Gain : Conn_01x02_Female; Pin_Header_Straight_1x02_Pitch2.54mm
I_LO: IQ_SDR-rescue_Conn_01x01-Connector_Generic-IQ_SDR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; Pin_Header_Straight_1x01_Pitch2.54mm
I_in+: IQ_SDR-rescue_Conn_01x01-Connector_Generic-IQ_SDR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; Pin_Header_Straight_1x01_Pitch2.54mm
I_in-: IQ_SDR-rescue_Conn_01x01-Connector_Generic-IQ_SDR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; Pin_Header_Straight_1x01_Pitch2.54mm
I_sig: IQ_SDR-rescue_Conn_01x01-Connector_Generic-IQ_SDR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; Pin_Header_Straight_1x01_Pitch2.54mm
J3: 35RAPC4BHN2; SWITCHCRAFT_35RAPC4BHN2
J6: Conn_Coaxial; BNC_Socket_TYCO-AMP
J17: IQ_SDR-rescue_Conn_01x01-Connector_Generic-IQ_SDR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; Pin_Header_Straight_1x01_Pitch2.54mm
JP1, JP3, JP4: Jumper_NC_Small-Device; Pin_Header_Straight_1x02_Pitch2.54mm
JP2: Jumper_NC_Small; Pin_Header_Straight_1x02_Pitch2.54mm
L1, L3: 1.3uH; L_Toroid_Vertical_L10.0mm_W5.0mm_P5.08mm
L2: 150nH; L_Toroid_Vertical_L10.0mm_W5.0mm_P5.08mm
Q1, Q2: BSS138; SOT-23
Q3: MMBT2222A-MMBT2222A; SOT-23
Q_LO: IQ_SDR-rescue_Conn_01x01-Connector_Generic-IQ_SDR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; Pin_Header_Straight_1x01_Pitch2.54mm
Q_in+: IQ_SDR-rescue_Conn_01x01-Connector_Generic-IQ_SDR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; Pin_Header_Straight_1x01_Pitch2.54mm
Q_in-: IQ_SDR-rescue_Conn_01x01-Connector_Generic-IQ_SDR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; Pin_Header_Straight_1x01_Pitch2.54mm
Q_sig: IQ_SDR-rescue_Conn_01x01-Connector_Generic-IQ_SDR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; Pin_Header_Straight_1x01_Pitch2.54mm
R1, R2, R7, R8, R19: 1k; R_0805
R3, R4, R5, R6: 50; R_0805
R9, R18, R20, R21, R22, R23: 10k; R_0805
R10, R11, R24, R25: 12k; R_0805
Resistor Bias: IQ_SDR-rescue_Conn_01x01-Connector_Generic-IQ_SDR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; Pin_Header_Straight_1x01_Pitch2.54mm
U1: Si5351A-B-GT; MSOP-10_3x3mm_Pitch0.5mm
U2: SN74CBT3253; SOIC-16W_5.3x10.2mm_Pitch1.27mm
U3, U4: INA821ID; SOIC-8_3.9x4.9mm_Pitch1.27mm
U6, U7: LM4562; SOIC-8_3.9x4.9mm_Pitch1.27mm
Y1: CX3225; Crystal_SMD_2520-4pin_2.5x2.0mm

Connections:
+3V3: A1.17, C1.1, C3.1, Q1.1, Q2.1, R1.1, R2.1, R9.1, U1.1, U1.7
+4.3V: C5.2, C6.2, C16.2, C17.1, C22.1, C27.1, Emit..1, JP1.1, Q3.2, R20.1, R22.2, U2.16, U3.8, U4.8, U6.8, U7.8
+5V: A1.27, C2.2, Col.1, JP1.2, Q3.3, R18.1, R19.2
/BP_Filter_o: L3.2, R22.1, R23.2, Resistor Bias.1, U2.7, U2.9
/I_LO: I_LO.1, U1.9, U2.14
/Q_LO: Q_LO.1, U1.6, U2.2
/SCL_3V: Q1.2, Q2.2, R1.2, R2.2, R9.2, U1.4, U1.5
/SCL_5V: A1.23, A1.24, Q1.3, Q2.3, R18.2
GND: C1.2, C2.1, C3.2, C4.1, C5.1, C6.1, C8.2, C9.2, C10.2, C11.2, C16.1, C17.2, C18.2, C19.2, C20.2, C21.2, C22.2, C23.1, C24.1, C27.2, JP2.1, JP3.1, JP4.1, L2.2, R21.2, R23.1, U1.8, U2.1, U2.8, U2.15, U3.5, U4.5, U6.4, U7.4, Y1.2, Y1.4
GNDA: C9.1, C10.1, U3.6, U4.6, U6.1, U6.2
unnamed: A1.4, A1.29, JP4.2
unnamed: C4.2, Q3.1, R19.1
unnamed: C7.1, L1.1
unnamed: BPF.1, C7.2, J6.1
unnamed: C8.1, R20.2, R21.1, U6.3
unnamed: C11.1, C13.1, L1.2, L2.1
unnamed: C13.2, L3.1
unnamed: C18.1, I_in-.1, R4.1, U3.1
unnamed: C19.1, I_in+.1, R3.1, U3.4
unnamed: C20.1, Q_in-.1, R5.1, U4.1
unnamed: C21.1, Q_in+.1, R6.1, U4.4
unnamed: C23.2, R25.1, U7.3
unnamed: C24.2, R24.1, U7.6
unnamed: C25.1, C28.1, U7.1, U7.2
unnamed: C25.2, R11.1, R25.2
unnamed: C26.1, C29.1, U7.5, U7.7
unnamed: C26.2, R10.1, R24.2
unnamed: C28.2, J3.2
unnamed: C29.2, J3.3
unnamed: Gain.1, R7.2, U3.3
unnamed: Gain.2, R7.1, U3.2
unnamed: Gain.1, R8.2, U4.3
unnamed: Gain.2, R8.1, U4.2
unnamed: J3.1, JP3.2
unnamed: J6.2, JP2.2
unnamed: I_sig.1, R11.2, U3.7
unnamed: Q_sig.1, R10.2, U4.7
unnamed: J17.1, U1.10
unnamed: R3.2, U2.6, U2.10
unnamed: R4.2, U2.3, U2.13
unnamed: R5.2, U2.4, U2.12
unnamed: R6.2, U2.5, U2.11
unnamed: U1.2, Y1.1
unnamed: U1.3, Y1.3

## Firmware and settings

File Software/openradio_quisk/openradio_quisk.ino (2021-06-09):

#include <Wire.h>

#include <Wire.h>

#include <Wire.h>

#include <si5351.h>

/*
  OpenRadio Quisk Interface 
  Main
  This is used to provide a serial interface which Quisk SDR can talk to.
  
  Copyright (C) 2014 Mark Jessop <vk5qi@rfhead.net>

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
    For a full copy of the GNU General Public License, 
    see <http://www.gnu.org/licenses/>.

   Command Reference:
    ------------------
    All commands consist of an identifier, followed by one or more parameters delinieated by commas, then a newline.
    i.e.:
    COMMAND,<param1>,<param2><LF>
    
    A command will return OK<LF> if successful, and ERROR<LF> if not. Some commands (particuarly transmit commands)
    may take a significant amount of time to return.
    
    Sending a command which takes parameters, without sending the parameters, will return the set parameters.
    
    Frequency Settings:
    
    FREQ,<freq>     - Set the center freq of the receiver, in Hz.
    FREQPSK,<freq>    - Set the transmit frequency, in Hz.

    Modulation:
    All transmissions will time out after 10 minutes. (if we implement it)
    
    CARRIER,<ON/OFF>  - Transmit a carrier.
    PSK,<rate>,message  - Send message using Phase Shift Keying, with the specified symbol rate.
*/

#include <stdlib.h>
#include <string.h>
#include <errno.h>

#include <avr/pgmspace.h>

#warning __PGMSPACE_H_

#include <EEPROM.h>
#include <Wire.h>

#include "si5351.h"
#include "TimerOne.h"

#include "settings.h"
#include "pins.h"
#include "ring_buffer.h"

#define VERSION "0.3"

// Default output frequency
#define RX_FREQ 14100000
#define TX_FREQ 14100000
#define FREQ_LIMIT_LOWER 100000
#define FREQ_LIMIT_UPPER 30000000

#define SERIAL_BAUD     57600
//#define USE_JOHNSON_COUNTER  // Select this if you have a Johnson counter and need the Si5351 to make signals at 4*freq.

Si5351 si5351;

int tx_relay_state = 0;
int tx_state = 0;

static struct settings settings;

// Ring buffer for use with the interrupt-driven transmit buffer.
struct ring_buffer data_tx_buffer = { { 0 }, 0, 0};

/* Returns true if settings are valid */
static bool read_settings(void)
{
    uint8_t *p = (uint8_t *)&settings;
    int i = 0;

    while(i < sizeof(struct settings))
        *p++ = EEPROM.read(i++);

    return settings.magic == SETTINGS_MAGIC;
}

static void write_settings(void)
{
    uint8_t *p = (uint8_t *)&settings;
    int i = 0;

    // Invalidate checksum to guard against partial writes
    EEPROM.write(0, 0);

    while(i < sizeof(struct settings))
        EEPROM.write(i++, *p++);
}

// Input buffer for reading user input.
#define INPUTBUFLEN 64
//char inputBuffer[INPUTBUFLEN];
int inputBufferPtr = 0;
char tempBuffer[20]; // Buffer for string to int conversion.
String inputBuffer = "";

void setup(){
    // Initialise things.
    pinMode(TX_RX_SWITCH, OUTPUT);
    digitalWrite(TX_RX_SWITCH, LOW);
    pinMode(MODULATION, OUTPUT);
    digitalWrite(MODULATION, LOW);
    pinMode(LED, OUTPUT);
    digitalWrite(LED, LOW);

    Serial.begin(SERIAL_BAUD);
    Serial.setTimeout(1000 * 10);

    uint8_t rev_id = si5351_init();

    // Click the relay as an 'audible' startup indicator.
    digitalWrite(TX_RX_SWITCH, HIGH);
    delay(300);
    digitalWrite(TX_RX_SWITCH, LOW);

    if (!read_settings()) {
        //Serial.println(F("Resetting settings to defaults"));
        settings.magic = SETTINGS_MAGIC;
        settings.rx_freq = RX_FREQ;
        settings.tx_freq = TX_FREQ;
        settings.cal_factor = 1.0f;
    }

    set_rx_freq(settings.rx_freq);
    set_tx_freq(settings.tx_freq);


}

void loop(){
  if(Serial.available()){
    // Read in a byte.
    char inChar = (char)Serial.read();
    
    // Work out what the character is. If letters or numbers, add to
    // the buffer, if not, don't add.
    
    // If character is a newline, we have reached the end of the command.
    if( (inChar == '\n') || (inputBufferPtr>INPUTBUFLEN)){
      // Parse string
      if( parseCommand(inputBuffer)==0 ){
        Serial.println("OK");
      }else{
        Serial.println("ERROR");
      }
      inputBuffer = "";
      inputBufferPtr = 0;
    }else if( isalnum(inChar) || ispunct(inChar) || isblank(inChar) || inChar==4 ){
      // Add to the input buffer if printable and not a line ending.
      inputBuffer += inChar;
      inputBufferPtr++;
    }
  }
}

// CSV parser function. Splits input into arguments.
// I am so sorry...
int parseCommand(String input){
  int params = 0;
  
  if(input.length()<3){
    // No command is shorter than 3 characters. Error.
    return 1;
  }
  // At this point we have found some sort of command (maybe)
  

  // Search through for commas, populate an array of pointers, make pointer = -1 if nothing found.
  // NOTE: This is a horrible bit of code. If theres is a better way to do CSV parsing in Arduino, let me know!
  int separators[] = {-1,-1,-1,-1,-1,-1};

  separators[0] = input.indexOf(",");
  
  if(separators[0] != -1){ // If we find one comma, maybe there are more...
    int i = 1;
    while((separators[i-1] != -1) && i<6){
      params++;
      separators[i] = input.indexOf(",", separators[i-1]+1);
      i++;
    }
  
  }

  if(params==0){ // Either a request command or a command with no parameter
    if(input.startsWith("FREQPSK")){
      Serial.print("FREQPSK,"); Serial.println(settings.tx_freq);
      return 0;
    }else if(input.startsWith("FREQ")){
      Serial.print("FREQ,"); Serial.println(settings.rx_freq);
      return 0;
    }else if(input.startsWith("CAL")){
      Serial.print("CAL,"); Serial.println(settings.cal_factor,10);
      return 0;
    }else if(input.startsWith("VER")){
      Serial.print("VER,"); Serial.println("OpenRadio V1.1");
      return 0;
    }else{
      // No other commands are valid without parameters. Error
      return 1;
    }
  }else if(params==1){ // Commands with one argument.
    String param1 = input.substring(separators[0]+1); // Extract the argument for passing to the function.
    if(input.startsWith("FREQPSK")){
      return parsePSKFreq(param1);
    }else if(input.startsWith("FREQ")){
      return parseFreq(param1);
    }else if(input.startsWith("PSKFREQ")){
      return parsePSKFreq(param1);
    }else if(input.startsWith("CARRIER")){
      return parseCarrier(param1);
    }else if(input.startsWith("CHAN")){
      return set_channel(param1);
    }else{
      // No other commands are valid with only one parameter. Error
      return 1;
    }
  }else if(params==2){ // Commands with 2 parameters (PSK);
    String param1 = input.substring(separators[0]+1, separators[1]);
    String param2 = input.substring(separators[1]+1);
    
    if(input.startsWith("PSK")){
      return psk_transmit(param1,param2);
    }else{
      // No other commands are valid with only one parameter. Error
      return 1;
    }
  }

  return 1; // Cannot parse command, error.
}

int freqValid(uint32_t freq){
  return (freq>FREQ_LIMIT_LOWER) && (freq<FREQ_LIMIT_UPPER);
}

// Parse frequency, program radio.
int parseFreq(String input){
  unsigned long result = 0;
  unsigned long combinedresult = 0;
  char* endptr;
  
  input.toCharArray(tempBuffer,10);
  
  result = strtoul(tempBuffer,&endptr,10);
  // If strtoul fails to convert, *endptr contains the character which conversion failed on.
  // Otherwise, *endptr contains '\0'.
  if(*endptr != 0) return -1;
  
  if(freqValid(result)){
    set_rx_freq(result);
    Serial.print("FREQ,");Serial.println(result);
    return 0;
  }else{
    //Serial.println("Invalid input.");
    return -1;
  } 
}

// Carrier on/off
// This should transmit a carrier at an offset from the rx freq.
// We probably dont need this right now.
int parseCarrier(String carrier_str){
// TODO

}

// Transit a string of PSK (message) at (rate) baud.
// We need to figure out how to decide what the 'offset' from the RF freq is.
// Maybe add another command to set this?
int parsePSK(String rate, String message){
// TODO

}

// Set the frequency of the transmitted PSK signal.
// This is entirely independent of the receive chain, and we should
// be controlling if we want to lock this to within the RX passband 
// from within the client software.
int parsePSKFreq(String input){
  unsigned long result = 0;
  unsigned long combinedresult = 0;
  char* endptr;
  
  input.toCharArray(tempBuffer,10);
  
  result = strtoul(tempBuffer,&endptr,10);
  // If strtoul fails to convert, *endptr contains the character which conversion failed on.
  // Otherwise, *endptr contains '\0'.
  if(*endptr != 0) return -1;
  
  if(freqValid(result)){
    set_tx_freq(result);
    Serial.print("FREQPSK,");Serial.println(result);
    return 0;
  }else{
    //Serial.println("Invalid input.");
    return -1;
  } 

}


//
// Si5351 Helper Functions
//

uint8_t si5351_init(){
    si5351.init(SI5351_CRYSTAL_LOAD_8PF,0,0);
    si5351.set_pll(SI5351_PLL_FIXED, SI5351_PLLA);
    // Set output frequencies
    set_rx_freq(RX_FREQ);
    set_tx_freq(TX_FREQ);

    // Enable RX, and disable TX by default.
    si5351.output_enable(RX_CLOCK,1);
    si5351.output_enable(TX_CLOCK,0);
    si5351.output_enable(SPARE_CLOCK,0);

    // Read the status register and return the chip revision ID.
    si5351.update_status();
    return si5351.dev_status.REVID;

}

static void set_rx_freq(uint32_t freq)
{
    // Save actual value
    settings.rx_freq = freq; // (Hz)

#ifdef USE_JOHNSON_COUNTER
    // This is for models where quadrature mixer requires a 4X LO signal.
    si5351.set_freq(freq * settings.cal_factor * 4, SI5351_PLL_FIXED,
                    RX_CLOCK);
#else
  // This is for models that use the Si5351 to produce the I/Q on CLK0 and CLK1.
  unsigned long long pll_freq;
  unsigned long long new_freq = freq * 100;
  uint_fast8_t mult;

  Serial.print("\nfreq:\n");
//  Serial.print(new_freq); 
  // mult must be less than 128 (7 bits) according to documentation

  // mult of 50 only works for this frequency, needs to be changed for other frequencies
  mult = 50;
    
  pll_freq = mult*new_freq;
  
  si5351.set_freq_manual(new_freq, pll_freq, SI5351_CLK1);
  si5351.set_freq_manual(new_freq, pll_freq, SI5351_CLK2);
  // Now we can set CLK1 to have a 90 deg phase shift by entering
  // mult in the CLK1 phase register, since the ratio of the PLL to
  // the clock frequency is mult.
  si5351.set_phase(SI5351_CLK1, 0);
  si5351.set_phase(SI5351_CLK2, mult);
  // We need to reset the PLL before they will be in phase alignment
  si5351.pll_reset(SI5351_PLLA);
#endif
  // This is for switching bands in some models.
  if( freq <= 4000000) {
    digitalWrite(S0, HIGH);
    digitalWrite(S1, HIGH);
  }
  else if (freq <= 8000000) {
    digitalWrite(S0, LOW);
    digitalWrite(S1, HIGH);
  }
  else if (freq <= 16000000) {
    digitalWrite(S0, HIGH);
    digitalWrite(S1, LOW);
  }
  else {
    digitalWrite(S0, LOW);
    digitalWrite(S1, LOW);
  }       
}

static void set_tx_freq(uint32_t freq)
{
    // Save actual value
    settings.tx_freq = freq;

    // Let driver choose PLL settings. May glitch when changing frequencies.
    si5351.set_freq(freq * settings.cal_factor, TX_CLOCK);
}

void tx_enable(){
    si5351.output_enable(TX_CLOCK,1);
    tx_state = 1;
}

void tx_disable(){
    si5351.output_enable(TX_CLOCK,0);
    tx_state = 0;
}

void tx(){
    digitalWrite(TX_RX_SWITCH, HIGH);
    digitalWrite(LED, HIGH);
    tx_relay_state = 1;
}

void rx(){
    digitalWrite(TX_RX_SWITCH, LOW);
    digitalWrite(LED, LOW);
    tx_relay_state = 0;
}

#define MIN_CHANNEL 1
#define MAX_CHANNEL 30


#ifdef USE_FLASH
// From https://docs.google.com/spreadsheets/d/1KP5XsAHPCD2FsUW5RoqCfCJYRt2o03q6RN2TroPgEKk/edit#gid=0
const prog_uint16_t channel_list[] =
#else
const uint16_t channel_list[] =
#endif
        {8986, 8990, 8993, 8996, 9000, 9003, 9006, 9010, 9013, 9016, 9020, 9023, 9026,
        9030, 9033, 9036, 9040, 9043, 9046, 9050, 9053, 9056, 9060, 9063, 9066, 9070,
        9073, 9076, 9080, 9083};

int set_channel(String input)
{
  unsigned long chan = 0;
  char* endptr;
  
  input.toCharArray(tempBuffer,10);
  
  chan = strtoul(tempBuffer,&endptr,10);
  // If strtoul fails to convert, *endptr contains the character which conversion failed on.
  // Otherwise, *endptr contains '\0'.
  if(*endptr != 0) return -1;



    if (chan < MIN_CHANNEL || chan > MAX_CHANNEL) {
        return 1;
    }

#ifdef USE_FLASH
    uint32_t rx = (uint32_t)pgm_read_word_near(channel_list + chan-1) * 1000;
#else
    uint32_t rx = (uint32_t)channel_list[chan-1] * 1000;
#endif
    uint32_t tx = rx * 3 + 1500;

    set_rx_freq(rx);
    set_tx_freq(tx);

    // Save settings
    write_settings();

    Serial.print("CHAN,"); Serial.println(chan);
    return 0;
}

int psk_transmit(String param1, String param2){
  unsigned long baud_rate = 0;
  char* endptr;
  
  param1.toCharArray(tempBuffer,10);
  
  baud_rate = strtoul(tempBuffer,&endptr,10);
  // If strtoul fails to convert, *endptr contains the character which conversion failed on.
  // Otherwise, *endptr contains '\0'.
  if(*endptr != 0) return -1;

    tx();
    tx_enable();
    if (!bpsk_start(baud_rate)){
      tx_disable();
      rx();
        return 1;
    }
    delay(300); //  Short delay for RX sync to occur.
    // Push string into ring buffer for transmission.
    for(int i = 0; i<param2.length(); i++){
      store_char(param2.charAt(i),&data_tx_buffer);
    }
    // Send an EOT control character, then a newline, to signify the end of the message.
    store_char((char)4, &data_tx_buffer);
    store_char('\n', &data_tx_buffer);
    while(data_waiting(&data_tx_buffer)>0){}
    delay(300);
    bpsk_stop();
    tx_disable();
    rx();

    return 0;
}

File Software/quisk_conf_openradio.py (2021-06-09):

# OpenRadio v1.1 Quisk Configuration File
# 
# IMPORTANT: To be able to control the OpenRadio board from within Quisk,
# you will need to compile and upload the 'openradio_quisk' firmware, which
# is available from: https://github.com/darksidelemm/open_radio_miniconf_2015
#
# You will also need to install the pyserial package for python.
#

from __future__ import print_function
from __future__ import absolute_import
from __future__ import division


# SOUND CARD SETTINGS
#
# Uncomment these if you wish to use PortAudio directly
#name_of_sound_capt = "portaudio:(hw:2,0)"
#name_of_sound_play = "portaudio:(hw:1,0)"

# Uncomment these lines if you wish to use Pulseaudio
name_of_sound_capt = "pulse"
name_of_sound_play = "pulse"

# SERIAL PORT SETTINGS
# Set this as appropriate for your OS.
openradio_serial_port = "COM3"
openradio_serial_rate = 57600


# OpenRadio Frequency limits.
# These are just within the limits set in the openradio_quisk firmware.
openradio_lower = 100001
openradio_upper = 29999999

# OpenRadio Hardware Control Class
#
import serial,time
from quisk_hardware_model import Hardware as BaseHardware

class Hardware(BaseHardware):
  def open(self):
    # Called once to open the Hardware
    # Open the serial port.
    self.or_serial = serial.Serial(openradio_serial_port,openradio_serial_rate,timeout=3)
    print("Opened Serial Port.")
    # Wait for the Arduino Nano to restart and boot.
    time.sleep(2)
    # Poll for version. Should probably confirm the response on this.
    version = str(self.get_parameter("VER"))
    print("This should be the version printed next.")
    print(version)
    # Return an informative message for the config screen
    t = version + ". Capture from sound card %s." % self.conf.name_of_sound_capt
    return t

  def close(self):      
    # Called once to close the Hardware
    self.or_serial.close()

  def ChangeFrequency(self, tune, vfo, source='', band='', event=None):
    # Called whenever quisk requests a frequency change.
    # This sends the FREQ command to set the centre frequency of the OpenRadio,
    # and will also move the 'tune' frequency (the section within the RX passband
    # which is to be demodulated) if it falls outside the passband (+/- sample_rate/2).
    print("Setting VFO to %d." % vfo)
    if(vfo<openradio_lower):
      vfo = openradio_lower
      print("Outside range! Setting to %d" % openradio_lower)

    if(vfo>openradio_upper):
      vfo = openradio_upper
      print("Outside range! Setting to %d" % openradio_upper)

    success = self.set_parameter("FREQ",str(vfo))

    print("sample_rate =")
    print(sample_rate)
    # If the tune frequency is outside the RX bandwidth, set it to somewhere within that bandwidth.
    if(tune>(vfo + sample_rate/2) or tune<(vfo - sample_rate/2)):
      tune = vfo + 10000
      print("Bringing tune frequency back into the RX bandwidth.")

    if success:
      print("Frequency change succeeded!")
    else:
      print("Frequency change failed.")

    return tune, vfo

#
# Serial comms functions, to communicate with the OpenRadio board
#

  def get_parameter(self,string):
    string = string + "\n"
    self.or_serial.write(string.encode())
    return self.get_argument()
    #return string.encode()
        
  def set_parameter(self,string,arg):
    string = string+","+arg+"\n"
    self.or_serial.write(string.encode())
    if self.get_argument() == arg:
      return True
    else:
      return False
    
  def get_argument(self):
    data1 = self.or_serial.readline()
    # Do a couple of quick checks to see if there is useful data here
    if len(data1) == 0:
       return -1
        
    # Maybe we didn't catch an OK line?
    if data1.startswith(b'OK'):
       data1 = self.or_serial.readline()
        
    # Check to see if we have a comma in the string. If not, there is no argument.
    if data1.find(b',') == -1:
       return -1
    
    data1 = data1.split(b',')[1].rstrip(b'\r\n')
    print("data1 =")
    print(data1)
    
    # Check for the OK string
    data2 = self.or_serial.readline()
    if data2.startswith(b'OK'):
       return data1

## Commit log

2021-04-14 Add files via upload
    Added Circuit Description for Milestone 3
2021-04-14 Add files via upload
    Added preliminary SDR Schematic PDF file
2021-04-19 Added schematic files for v0.2
    Changes still need to be made.
    [ENGR357_Project.kicad_pcb, ENGR357_Project.sch, INA821ID.step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]
2021-04-19 Added v0.2 schematic
2021-04-23 Added schematic files for version 0.4
    [ENGR357_Project.kicad_pcb, ENGR357_Project.sch, ENGR357_Project_v0_3.sch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]
2021-04-25 Moved v0.1 files to there own directory
    [ENGR357_Project.kicad_pcb, ENGR357_Project.sch, INA821ID.step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]
2021-04-25 Added v1.0 Schematic Files
    [ENGR357_Project_v1.0.sch, INA821ID.step, INA821IDR.step]
2021-04-25 Simulates the main circuit setup
2021-04-27 Added v1.1 schematic files
    [ENGR357_Project.kicad_pcb, ENGR357_Project.sch, ENGR357_Project_v1.0.sch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]
2021-04-29 Create PCB Files
2021-04-29 Added PCB Files directory
    [ENGR357_Project_v1.1.kicad_pcb]
2021-06-01 Added PCB and schematic images
2021-06-07 v2.0 schematic added
    Make sure to open the right version, because the files are a bit disorganized
    [35RAPC4BHN2.step, ENGR357_Project.kicad_pcb, ENGR357_Project.sch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]

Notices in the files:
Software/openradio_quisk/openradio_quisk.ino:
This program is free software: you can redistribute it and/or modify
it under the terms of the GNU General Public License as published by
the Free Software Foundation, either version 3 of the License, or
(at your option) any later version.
